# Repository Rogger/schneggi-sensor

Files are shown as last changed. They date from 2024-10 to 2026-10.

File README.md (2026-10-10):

# Schneggi sensor 🐌 
A Zigbee sensor integrated with Home Assistant for monitoring temperature, humidity, and optional CO2.

- High accuracy temperature and humidity measurements ([Sensirion SHTC3](https://www.sensirion.com/products/catalog/SHTC3/))
- High accuracy CO2 measurement ([Sensirion SCD40](https://sensirion.com/products/catalog/SCD40)) - optional board
  - CO2 firmware exposes two temperatures: SHTC3 ambient temperature on endpoint 1
    and SCD40 temperature on endpoint 2. The SCD40 reading uses the same sample as
    CO2 and can be affected by self-heating and enclosure conditions; use SHTC3
    as the primary ambient reading. The existing SHTC3 humidity entity is unchanged.
- Low power consumption and long battery life for the non-CO2 variant
  - Hardware: nRF52840 chip, low-current linear regulator, battery monitor with on/off capability 
  - Software: Zigbee sleepy end device for the non-CO2 variant
  - Measured: 3uA average over 1 minute without CO2 (before OTA support)
- The non-CO2 variant can be powered with 3V to 6V (JST connector), e.g. 350mAh li-poly.
- The CO2 variant is USB-C powered. It advertises DC power, keeps its Zigbee receiver on while idle, and does not report a battery.
- Small footprint (3,5cm x 3cm )
- Tested with [Home Assistant](https://www.home-assistant.io/) and [SkyConnect](https://www.home-assistant.io/skyconnect/)

After upgrading CO2 firmware to a build with the second temperature endpoint,
Home Assistant ZHA must discover endpoint 2. Re-interview/reconfigure the device;
if the endpoint list remains cached, remove and pair the device again. Both
temperature entities use the standard Temperature Measurement cluster, so no
custom quirk is required. You can rename them in HA to **Temperature SHTC3** and
**Temperature SCD40**; endpoint 1 is SHTC3 and endpoint 2 is SCD40. The new reading
uses the same sampling interval, 0.1 °C fallback change threshold, daily refresh,
and standard Configure Reporting support as the existing temperature reading.

## Battery power management

The non-CO2 debug and production profiles enable I2C runtime power management.
The application enables it on the sensor bus; the TWIM driver suspends the
controller and applies its sleep pin configuration between transfers.
Polling, sampling intervals, and SHTC3 measurement accuracy are unchanged.

Failed SHTC3 fetches attempt a sleep command after a 13 ms settling delay,
working around the NCS 2.9.2 driver's missing error-path cleanup without changing
the shared SDK. Cleanup is best-effort: an inaccessible sensor cannot be forced
to sleep. The original fetch error is retained and no failed sample is reported.
The command and conversion timing follow the
[SHTC3 datasheet](https://sensirion.com/file/datasheet_shtc3).

Battery-profile rejoin delays grow from 1 second exponentially to a one-hour
cap (1, 2, 4, ..., 1024, 2048, 3600 seconds). Successful reconnection resets the
backoff. After prolonged outages, recovery may therefore wait up to an hour
before the next attempt, plus commissioning time. USB-powered CO2 profiles keep
their 15-minute cap and do not enable I2C runtime PM or battery monitoring.

Battery measurements run hourly in debug builds and daily in production builds.
If sampling or updating either battery attribute fails, the firmware retries on
the next sensor cycle (one or ten minutes respectively). A successful update
starts the next battery interval. The firmware attempts to disable the divider
on every path and logs cleanup failures.

The firmware restarts if Zigbee startup or scheduling a required measurement,
rejoin, or watchdog alarm fails, so it cannot stay running indefinitely without
that work. Ordinary join failures still use the rejoin backoff described above.
Alarm replacement removes previous instances and uses overflow-safe conversion
for the full supported sampling range of 1–1440 minutes. Repeated Identify
requests keep one blink alarm; scheduling failure stops the LED animation.

Validate on hardware before relying on battery-life estimates: compare at least
an hour of production-profile current capture before/after, with the debugger
disconnected; check repeated sensor reads, transient I2C failures, and recovery
after a prolonged coordinator outage. Host tests cannot verify physical sleep
current or bus suspend/resume behavior.

## Zigbee reporting

ZHA can configure the standard minimum interval, maximum interval, and
reportable change for endpoint 1's Temperature Measurement (`0x0402`) and
Relative Humidity Measurement (`0x0405`) measured-value (`0x0000`) attributes.
Their changes are in hundredths of a degree Celsius and hundredths of a percent
relative humidity. For settings that differ from ZBOSS's defaults, ZBOSS applies
them to every new sensor reading. Without a configuration, or after reporting
is restored to defaults, the firmware retains its 0.1 °C / 1% change thresholds
and 24-hour refresh. A request for ZBOSS's exact default settings (5-second
minimum, no periodic maximum, zero change) is indistinguishable from a reset
and also uses the firmware fallback.

The CO2 Concentration Measurement (`0x040D`) measured value is refreshed on
every sample, so its Zigbee minimum and maximum reporting intervals can be
configured. NCS 2.9.2's ZBOSS treats the single-precision CO2 value as a
changed/unchanged attribute and does not apply a numeric reportable-change
threshold to it. The sensor still samples every minute in debug builds and
every ten minutes in production builds; configuring a shorter reporting
interval does not produce a newer measurement.

## PCB
The PCB was designed with KiCad 7 and manufactured/assembled with JLCPCB. All relevant files can be found in the [repo](hardware)

base
co2

## HomeAssistant



## Case




## Build
This project uses a **west workspace** (manifest in `west.yml`) and a local Makefile wrapper.

### 1) One-time workspace setup
From the project directory:

```bash
west init -l .
make west-update
```

This initializes a west workspace in the parent directory and fetches all required modules
(including `modules/sensirion_drivers` for SCD4X/CO2 builds).

The Makefile uses the parent west workspace when `../.west` exists. To use a
different NCS workspace, pass `NCS_WORKSPACE=/path/to/workspace`.
Builds compare the cached sysbuild source with the selected NCS workspace and
regenerate incompatible project build directories automatically. West's
automatic pristine mode handles other cache incompatibilities.

### 2) Build
Firmware builds now include signed MCUboot/Zigbee OTA support. Supply
`OTA_SIGNING_KEY=/absolute/private/schneggi.pem` to the build commands below.
For development only, use `OTA_ALLOW_TEST_KEY=ON` to opt into the public SDK key.
See [OTA setup, signing, ZHA configuration, and recovery](docs/ota.md).
Interrupted transfers can resume from the last completed 4 KiB flash page after
retrying Install in Home Assistant, including after a sensor power cycle. The
running firmware must already include resume support.

```bash
cd <project-dir>
make build-debug OTA_ALLOW_TEST_KEY=ON
```

Default output:
- `build_debug/merged.hex`
- `build_debug/schneggi-sensor/zephyr/zephyr.elf`

### Build Profiles

Convenience targets:

- `make build-debug`
  - Debug build without CO2 / SCD4X
- `make build-debug-co2`
  - Debug build with CO2 / SCD4X
- `make build-production`
  - Production build without CO2 / SCD4X
- `make build-production-co2`
  - Production build with CO2 / SCD4X

Equivalent flash targets:

```bash
make flash-debug
make flash-debug-co2
make flash-production
make flash-production-co2
```

For the CO2 production firmware:

```bash
make build-production-co2 OTA_SIGNING_KEY=/absolute/private/schneggi.pem
make flash-production-co2
```

### 3) Test (host unit tests)

```bash
make test
```

The host tests cover reporting thresholds and counter wraparound, battery conversion,
CO2 attribute validation, Zigbee signal handling, OTA behavior for both power profiles,
and rejoin retry/cancellation behavior. They also exercise sensor fetch/read failures,
failed attribute writes, custom reporting and resets, exact fixed-point conversion,
battery ADC/GPIO error cleanup and retry timing, and OTA package validation/index updates.
OTA resume tests simulate resets throughout a download, torn flash writes and
checkpoint commits, corrupted saved data, and maximum-size images.
Runtime tests cover failed startup, alarm exhaustion, cancellation failures,
duplicate reconnect signals, and long scheduling intervals. The Python suite also
checks that PCB rule-check failures prevent manufacturing exports under parallel make.
CI runs them in Debug and Release and builds all four firmware profiles. ADC/GPIO
behavior, network recovery over the radio, and sleep current still require hardware tests.

Version tags also run the [GitHub release workflow](docs/releases.md), which publishes
clearly labeled public-development-key firmware, a ready-to-copy ZHA OTA ZIP,
and checksums after validation. Releases preserve the separate CO2/non-CO2 firmware versions.

`make clean` accepts only `build` or `build_*` directories inside this project.

### 4) Flash

```bash
make flash-debug
```

For a specific J-Link probe:

```bash
make flash-production-co2 SNR=<your_jlink_serial>
```

### Useful overrides

```bash
make build BUILD_DIR=build_custom
make build CONF_FILE=prj_production_no_scd4x.conf OVERLAY='boards/adafruit_feather_nrf52840.overlay;boards/no_scd4x.overlay'
make build-production-co2 NCS_WORKSPACE=/path/to/workspace
make flash SNR=<your_jlink_serial>
```

### Keep dependencies in sync
After updating `west.yml`:

```bash
make west-update
```

## Resources
- The PCB design was inspired by [Getting Started With nRF52 MCU in a PCB](https://resources.altium.com/p/getting-started-nrf52-mcu-pcb#getting-started-schematics)
- The repos [zigbee-plant-sensor](https://github.com/stanvn/zigbee-plant-sensor) and [b-parasite](https://github.com/rbaron/b-parasite) are a great start
- The [Zyphr driver for SCD40](https://github.com/nobodyguy/sensirion_zephyr_drivers) 
- The [nRF Sniffer](https://developer.nordicsemi.com/nRF_Connect_SDK/doc/latest/nrf/protocols/zigbee/tools.html) with [https://www.wireshark.org](Wireshark) is a helpful tool to debug Zigbee communication
- The [ZigBee specification 22 1.0](https://csa-iot.org/wp-content/uploads/2022/01/docs-05-3474-22-0csg-zigbee-specification-1.pdf) and [ZigBee Cluster Library R8](https://zigbeealliance.org/wp-content/uploads/2021/10/07-5123-08-Zigbee-Cluster-Library.pdf)

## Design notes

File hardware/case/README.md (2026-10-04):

# Schneggi sensor case

`bottom.stl` and `top.stl` are the printable enclosure parts for the latest PCB.
Keep their relative placement when reviewing the assembly in a CAD viewer or
slicer.

No editable CAD source or generator for these parts is included in this repository.

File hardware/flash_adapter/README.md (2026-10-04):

# Flash Adapter PCB

This KiCad project is intended to be exported for JLCPCB with KiCad 9.

Use KiCad 9 from your `PATH`:

```sh
kicad-cli version
```

The expected version for the checked-in production files is KiCad CLI `9.0.9`.

## Generate JLCPCB Files

These commands follow JLCPCB's KiCad 9 Gerber/drill preparation guidance:

- Run DRC before generating manufacturing files.
- Export the standard fabrication layers: copper, paste, silkscreen, solder mask, and `Edge.Cuts`.
- Use Protel filename extensions for Gerbers.
- Use extended X2 format and include netlist attributes.
- Generate Excellon drill output with absolute origin, millimeters, decimal zeros format, and alternate oval-hole mode.
- Use the drill/place-file origin so Gerber, drill, and CPL coordinates are positive and board-relative.
- Format the BOM as `Comment,Designator,Footprint,JLCPCB Part #（optional）`.
- Format the CPL as `Designator,Mid X,Mid Y,Layer,Rotation`, with `mm` coordinate suffixes.
- Zip only the Gerber layers and merged Excellon drill file before upload.

Reference: <https://jlcpcb.com/help/article/how-to-generate-gerber-and-drill-files-in-kicad-9>
BOM sample: <https://static.jlcpcb.com//video/Sample-BOM_JLCSMT.xlsx>
CPL sample: <https://static.jlcpcb.com//video/JLCSMT_Sample_CPL1.xlsx>

From `hardware/flash_adapter`:

```sh
make jlcpcb
```

The `Makefile` stops before export if DRC errors or ERC violations are found.
It runs the sequence below. For an AppImage installation, override the command:

```sh
make jlcpcb KICAD_CLI='/path/to/AppRun kicad-cli'
```

```sh
kicad-cli pcb drc --severity-error --schematic-parity --exit-code-violations --output flash_adapter-drc.rpt flash_adapter.kicad_pcb
kicad-cli sch erc --severity-all --exit-code-violations --output flash_adapter-erc.rpt flash_adapter.kicad_sch

rm -f jlcpcb/gerber/*
kicad-cli pcb export gerbers --output jlcpcb/gerber --layers F.Cu,B.Cu,F.Paste,B.Paste,F.Silkscreen,B.Silkscreen,F.Mask,B.Mask,Edge.Cuts --use-drill-file-origin flash_adapter.kicad_pcb
kicad-cli pcb export drill --output jlcpcb/gerber --format excellon --drill-origin plot --excellon-units mm --excellon-zeros-format decimal --excellon-oval-format alternate flash_adapter.kicad_pcb
kicad-cli sch export bom --fields Value,Reference,Footprint,'LCSC Part' --labels Comment,Designator,Footprint,'JLCPCB Part #（optional）' --output jlcpcb/production_files/BOM-flash_adapter.csv flash_adapter.kicad_sch
sed -i 's/"//g' jlcpcb/production_files/BOM-flash_adapter.csv

kicad-cli pcb export pos --side front --format csv --units mm --smd-only --use-drill-file-origin --output /tmp/CPL-flash_adapter.raw.csv flash_adapter.kicad_pcb
awk -F, 'BEGIN { print "Designator,Mid X,Mid Y,Layer,Rotation" } NR > 1 { gsub(/"/, ""); layer = ($7 == "top" ? "Top" : ($7 == "bottom" ? "Bottom" : $7)); printf "%s,%.4fmm,%.4fmm,%s,%.0f\n", $1, $4, $5, layer, $6 }' /tmp/CPL-flash_adapter.raw.csv > jlcpcb/production_files/CPL-flash_adapter.csv

rm -f jlcpcb/production_files/GERBER-flash_adapter.zip
zip -j -q jlcpcb/production_files/GERBER-flash_adapter.zip jlcpcb/gerber/*.gtl jlcpcb/gerber/*.gbl jlcpcb/gerber/*.gtp jlcpcb/gerber/*.gbp jlcpcb/gerber/*.gto jlcpcb/gerber/*.gbo jlcpcb/gerber/*.gts jlcpcb/gerber/*.gbs jlcpcb/gerber/*.gm1 jlcpcb/gerber/*.drl
```

The Gerber package uses JLCPCB-style Protel extensions and a single merged Excellon drill file.
The BOM and CPL match the JLCPCB sample column names and column order.

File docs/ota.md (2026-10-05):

# Firmware updates through Home Assistant ZHA

Schneggi uses NCS 2.9.2's Zigbee FOTA client on endpoint 5, cluster `0x0019`,
and MCUboot with ECDSA P-256 signatures and swap using move. Endpoint 1 retains
the sensor clusters. Home Assistant supplies the image and starts installation
through its firmware update entity. No custom ZHA quirk is required by this design.

## One-time installation and signing key

Existing firmware has no OTA bootloader. Install the first OTA-capable
`merged.hex` using the wired programmer. Application-only HEX/BIN files cannot
perform this migration. Back up device flash before migration if retaining the
existing pairing is important; do not use `erase` or `erase-and-flash`.

Generate an ECDSA P-256 private key with MCUboot's `imgtool keygen -t ecdsa-p256
-k /absolute/private/schneggi.pem` (available in the NCS toolchain environment).
Keep this key outside the repository and retain a secure backup. The same key
must sign all subsequent updates for devices installed with it. Losing or
changing it requires another wired installation; bootloader OTA is not supported.

```sh
make build-production OTA_SIGNING_KEY=/absolute/private/schneggi.pem
make flash-production
```

Use `build-production-co2` / `flash-production-co2` for the CO2 board.
Select the correct programmer with `SNR=...`. Flash commands program and erase
only affected sectors. The partition layout keeps ZBOSS network data at
`0xf7000–0xfefff` and product configuration at `0xff000–0xfffff`.
Pairing retention through migration still needs validation on the device.

For a disposable development device, explicitly opt into the publicly known
SDK key:

```sh
make build-debug OTA_ALLOW_TEST_KEY=ON
```

CI artifacts and automated GitHub release assets also use that public key and
are labeled as development firmware, including the production power profiles.
`OTA_ALLOW_TEST_KEY` defaults to `OFF`; ordinary builds
require a private key. Use a separate build directory when changing signing keys.

## Build an update

Increase `CONFIG_MCUBOOT_IMGTOOL_SIGN_VERSION` in the desired profile's `prj_*.conf`,
for example from `1.0.0` to `1.0.1`. Keep debug and production versions aligned
within each hardware variant; CO2 and non-CO2 have separate version histories.
Rebuild with the original signing key:

```sh
make build-production OTA_SIGNING_KEY=/absolute/private/schneggi.pem
make ota-package BUILD_DIR=build_production
make verify-ota BUILD_DIR=build_production OTA_SIGNING_KEY=/absolute/private/schneggi.pem
```

This creates `build_ota_package/index.json` and the corresponding `.zigbee` file.
To create a combined index for both production variants:

```sh
python3 scripts/package_ota.py build_production build_production_co2
```

The tool validates the OTA header, hardware/profile identifiers, image sizes,
the generated DFU payload (one application image with ID 0 and its exact size),
and agreement between MCUboot and Zigbee versions. Conflicting filenames or
existing firmware are rejected before staging files. Firmware files and the index
are installed atomically, so interrupted writes can be retried. Identical firmware
files are left untouched when packaging again.
MCUboot verifies the cryptographic signature on-device before booting a candidate.
The index includes a checksum for ZHA's file-integrity validation.

Versions use `major.minor.patch`, encoded as `(major << 24) | (minor << 16) | patch`.
Major and minor are 8-bit fields; patch is 16-bit. Do not use a `+build` suffix:
Nordic's Zigbee version ignores that suffix. Equal and older versions are refused
by the OTA client. To distribute a fix that restores earlier behavior, release
that code with a new, higher version. Automatic MCUboot trial rollback is separate
from this OTA version policy.

| Profile | Image type |
| --- | --- |
| Production, without CO2 | `0x0101` |
| Production, with CO2 | `0x0102` |
| Debug, without CO2 | `0x8101` |
| Debug, with CO2 | `0x8102` |

Hardware version is `1`. Manufacturer ID `0xFFF1` is a development identifier,
not a CSA assignment to FuZZi. Keep this feed private to your devices; a commercial
release should use an assigned manufacturer ID. The index also matches the
`FuZZi` manufacturer name and `Schneggi Sensor` model. Changing these identifiers
or moving between profiles requires a deliberate migration, normally wired.

Starting with 1.0.2, OTA files and indexes omit the optional minimum/maximum
hardware-version range. NCS 2.9.2's periodic Query Next Image request omits its
hardware version, and zigpy rejects a restricted image when that field is absent.
Removing only the range from the index is insufficient: zigpy also checks the
downloaded OTA header. Compatibility is enforced by manufacturer and image type;
the four image types above are reserved for these hardware-version-1 profiles.
Assign new image types for future incompatible hardware. The client's hardware
version remains 1 for queries triggered by Image Notify. The packager continues
to accept older files with a hardware range of 1–1 for manual notification tests.

## Configure ZHA

Copy the contents of `build_ota_package/` into `/config/zigbee_ota/` on the Home
Assistant host. These are paths **inside Home Assistant**, not on the build PC.
For a different destination, generate the index with `--ha-directory /your/path`.
Merge this into `configuration.yaml`, preserving any existing ZHA configuration:

```yaml
zha:
  zigpy_config:
    ota:
      extra_providers:
        - type: zigpy_local
          index_file: /config/zigbee_ota/index.json
```

Restart Home Assistant to load the provider. After the initial wired migration,
check that ZHA sees endpoint 5's OTA client cluster. Re-interview/reconfigure the
device if needed; if the cached endpoint list remains stale, removal and pairing
again may be necessary. Confirm that the device has a firmware update entity.

The device discovers the OTA server on joining/rebooting, retries discovery every
24 hours if necessary, and queries a discovered server hourly. ZHA can then show
the newer image. Select **Install** on the update entity. Sleepy-device polling
on the non-CO2 variant can delay the start; a missed notification may require
retrying after the device wakes. Its production long polling interval is two
minutes. CO2 firmware from 2.0.0 keeps the receiver on while idle, so it should
accept the notification promptly.

The 2.0.0 CO2 image also changes endpoint 1's power source to DC, removes its
Power Configuration cluster, and increments the endpoint descriptor version.
After updating an existing device, reconfigure or re-interview it in ZHA so the
cached battery entity can be removed. If ZHA keeps the old cluster list, remove
and pair the device again.

To test automatic discovery from 1.0.1, publish the 1.0.2 package and restart
Home Assistant to load its index. Keep the sensor powered and wait for its next
hourly query; do not send the manual Image Notify command. Confirm that ZHA shows
`0x01000002`, then install it. The firmware entity may remain `unknown` until a
query is received. A successfully loaded provider alone does not establish that
the image matches the sensor. Enable ZHA debug logging to inspect the query and
image selection if discovery does not occur.

The battery variant uses a temporary 100 ms polling interval during transfers,
then restores its normal interval on error or completion. The USB-powered CO2
variant leaves its receiver on and does not use the sleepy-device polling controls.
During download, five minutes without an accepted image block causes an abort and
reboot to clear the session. Successful image validation cancels that deadline;
ZBOSS then honors the server's installation time, including indefinite deferral.
A separate five-minute deadline resets the session by rebooting if the server's
Upgrade End response is missing. It checks the ZBOSS state, so an acknowledged
indefinite deferral or scheduled installation does not trigger recovery.
The battery client uses a bounded 30-second turbo-poll window to receive the
Upgrade End response, then returns to normal polling while waiting. The USB
variant keeps receiving continuously. CO2 firmware from 2.0.4 and non-CO2 firmware
from 1.0.6 support OTA resume and retain completed
4 KiB flash pages across server aborts, timeout recovery, and device power loss.
Retry **Install** in Home Assistant after the sensor reconnects. Each retry first
downloads and compares the OTA and DFU headers, then jumps to the last committed
page. The incomplete page is downloaded again. Before the first page has been
committed, a retry starts from zero. Home Assistant may initially display 0% until
the device advances its requested offset.

The checkpoint journal uses the existing reserved page at `0xf6000`; neither
MCUboot slots nor Zigbee storage move. Each committed page has a CRC-protected
record written after its data, with a separate commit marker. Incomplete journal
records are ignored. Corrupt stored data, an invalid journal header, a changed
package header, or a different image identity cause a fresh download. Invalid
incoming images discard their checkpoint.
Firmware images must remain immutable for a given manufacturer, image type,
version and size; publish changed contents with a higher version. MCUboot still
verifies the candidate signature before booting it, and trial firmware cannot
write the secondary slot until confirmation. The receiver accepts the same
canonical, single-application DFU packages as `scripts/package_ota.py`.

The firmware currently running on the sensor must include this resume code;
installing it from older firmware uses that older client's restart behavior.
Successful leave events discard retained progress. If a transfer or installation
is active, the device also aborts and reboots after normal leave handling to clear
SDK protocol state; failed leave attempts preserve the session.
Installation briefly interrupts sensor reporting and then rejoins using
persistent network settings.

See [ZHA firmware updates](https://www.home-assistant.io/integrations/zha/#ota-updates-of-zigbee-device-firmware)
and [zigpy provider configuration](https://github.com/zigpy/zigpy/wiki/OTA-Configuration).
An HTTPS index via `zigpy_remote` can be added later. The [release workflow](releases.md)
publishes downloadable assets, including a ZIP for the local ZHA provider; it does
not change Home Assistant remotely.

## Recovery, flash limits, and hardware acceptance

Bench test on 2026-09-28: the USB-powered debug CO2 sensor successfully updated
from 1.0.0 to 1.0.1 through ZHA after a manual Image Notify. The installed version
changed to `0x01000001`, CO2/temperature/humidity reporting resumed, and reporting
and pairing survived a subsequent power cycle. The first installation attempt
failed; the retry completed. On 2026-10-01, ZHA discovered the 1.0.2 image after
its local provider was updated, without a manual Image Notify. Installation again
started on the second attempt, and Home Assistant reported `0x01000002` with
changing sensor readings. This confirms automatic discovery and the basic update
path for that device. The remaining recovery tests below require separate validation.

The 1 MiB internal flash contains a 48 KiB bootloader, two 468 KiB slots, a
reserved page, and the existing 36 KiB Zigbee storage. The image-size check allows
460 KiB including the MCUboot header/signature, reserving pages for move-swap and
its trailer. Keep `pm_static.yml` unchanged for future OTA releases.

MCUboot requests a trial boot. New downloads and image blocks are rejected until
the running image is confirmed, protecting the previous firmware in the secondary
slot. A later OTA query can retry after confirmation. Ten seconds after Zigbee
stack startup, the application confirms the candidate only if required peripheral
devices are ready, plus battery-monitor initialization on non-CO2 firmware.
This is a local startup check, not a test of successful sensor conversions or
coordinator reachability. Failure reboots without confirmation so MCUboot can
revert. A 120-second hardware watchdog is fed by the Zigbee scheduler every 30
seconds to recover from a hang; MCUboot feeds it during swaps. A fault after
confirmation does not automatically
restore the old application.

The health alarm wakes the battery variant every 30 seconds, and its watchdog
stays active during sleep. Previously published current measurements predate OTA
support. Measure idle current again and allow for higher radio current during
updates.

Before deploying to all sensors, test on one device of each hardware variant:

1. Save the current flash, install the initial merged image, and verify sensor
   reporting, retained pairing (or re-pair), and ZHA's OTA endpoint/update entity.
2. Install a higher-version image through ZHA; verify the reported version,
   confirmation, reconnection, and temperature/humidity reporting. Check CO2
   readings on the USB variant and battery reporting on the non-CO2 variant.
3. Interrupt the coordinator during download. Verify timeout recovery and a
   successful retry from the committed offset, with normal polling restored on
   the battery variant. The sensor log reports `Resuming OTA at byte ...`.
4. Interrupt device power during transfer and during the swap. Verify a working
   old or new image and intact pairing data after restart. Retry the interrupted
   download and verify a nonzero requested offset after the headers are received.
5. Offer a wrong-profile image, an older image, a corrupted image, and an image
   signed with a different key. Verify rejection and recovery.
6. Use a deliberately failing trial image on the test device to verify rollback
   after failed startup and watchdog reset; retain wired recovery access.
7. Measure production idle/update current with the debugger disconnected.
8. Drop the Upgrade End response and verify recovery after five minutes. Then
   explicitly defer installation (indefinitely and for more than five minutes)
   and verify that neither case triggers the missing-response recovery.
9. Exercise failed and successful leave attempts during download and deferred
   installation. Failed attempts must preserve the session; successful leaves
   must reset it without executing a stale deferred installation.

Host tests and builds do not establish radio interoperability, physical power-loss
recovery, or battery lifetime. Those checks require the sensor and a running ZHA
installation.

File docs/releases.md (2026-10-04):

# GitHub firmware releases

The **Release firmware** workflow creates a GitHub Release when a version tag
such as `2.0.3` or `v2.0.3` is pushed. It tests and builds the exact tagged commit,
using the same workflow as branch/PR CI. Debug and Release host tests, all four
firmware builds, signature verification, and OTA packaging must succeed before
anything is published.

All downloadable images use the **public MCUboot SDK development key**. This is
also true for the production power profiles; the profile name is not a security
designation. These images can OTA-update devices installed with that same key
and image type. Devices installed with a private key need separately signed
builds. See [OTA setup and compatibility](ota.md).

## Publish a new version

1. Increase `CONFIG_MCUBOOT_IMGTOOL_SIGN_VERSION` in both debug and production
   configurations for each variant that changed. CO2 and non-CO2 have separate
   version histories; leave an unchanged variant's version alone. Merge the
   changes into `main` after testing.
2. Tag that commit and push the tag, for example:

   ```sh
   git switch main
   git pull --ff-only
   git tag -a 2.0.3 -m 'Schneggi 2.0.3'
   git push origin 2.0.3
   ```

3. Follow **Actions → Release firmware**. Once validation and uploads finish,
   the workflow publishes the release with generated change notes, the source
   commit, per-profile versions, and the public-key notice.

The repository tag labels a source snapshot; it does not override firmware
versions. For example, a `2.0.3` release may contain CO2 `2.0.3` and non-CO2
`1.0.5`. Increase each affected variant's firmware version before tagging, or
existing devices running that version will refuse the OTA update.

Alternatively, use **Actions → Release firmware → Run workflow**, select `main`,
and enter an existing tag. It must point to a commit containing the release
packaging scripts. This creates a release for a tag that has not yet been
published. Tags support `major.minor.patch` with an optional `v` prefix; suffixes
such as `-rc1` are not supported by this workflow.

## Downloadable assets

| Asset | Purpose |
| --- | --- |
| `schneggi-ota-public-test-key.zip` | All four `.zigbee` images and `index.json`, ready to extract into HA's `/config/zigbee_ota/` |
| Individual `.zigbee` files and `index.json` | The same local-provider OTA package as separate downloads |
| `schneggi-<profile>-<version>-public-test-key-merged.hex` | Wired installation including MCUboot |
| `schneggi-<profile>-<version>-public-test-key-signed.bin` | Signed application only |
| `schneggi-<profile>-<version>-public-test-key-partitions.yml` | Flash layout for each build |
| `FIRMWARE.md` | Source commit, versions, signing-key notice, and installation guidance |
| `SHA256SUMS` | SHA-256 checksums of all the other assets |

The same flat set of files is available from normal CI under the Actions artifact
`development-firmware-public-test-key`. No local build environment is needed to
download and use them. Home Assistant still needs the [local OTA provider](ota.md#configure-zha)
configured and the package copied to its configuration directory.

## Failed runs and retries

A failed build does not create a release. Publication starts with a draft and
only makes it public after all uploads succeed. A rerun may replace matching
assets in that draft to complete a failed upload. It refuses to modify an already
published release: use a new tag and bump affected firmware versions for fixes.
Existing draft release notes are preserved; newly created drafts include the
firmware notice and GitHub-generated change notes. Do not move a tag during a run;
the workflow verifies that it still points to the commit that was built.

Only the publishing job has `contents: write`; test/build jobs have read access.
The built-in `GITHUB_TOKEN` handles publication, so no extra token or signing
secret is required for these public-key development releases.

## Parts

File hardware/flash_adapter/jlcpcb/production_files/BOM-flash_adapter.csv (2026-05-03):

Comment | Designator | Footprint | JLCPCB Part #（optional）
FTSH-105-01-L-DV-K-TR | J1 | schneggi_library:CONN-SMD_FTSH-105-01-L-DV-K-TR | C448647
HX PZ2.54-2x5P WT | J2 | easyeda_import:HDR-SMD_10P-P2.54-H-M-R2-C5-W18.0 | C46061687

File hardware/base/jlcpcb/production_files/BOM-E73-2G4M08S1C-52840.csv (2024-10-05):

Comment | Designator | Footprint | LCSC
100nF | C3 | C_0603_1608Metric | C14663
1uF | C1 | C_0603_1608Metric | C15849
SM04B-SRSS-TB (LF)(SN) | CN2 | CONN-SMD_4P-P1.00_SM04B-SRSS-TB-LF-SN | C160404
180k | R9 | R_0603_1608Metric | C22827
1M0 | R10,R3 | R_0603_1608Metric | C22935
220 | R4 | R_0603_1608Metric | C22962
2.2uF | C2 | C_0603_1608Metric | C23630
10k | R5,R6 | R_0603_1608Metric | C25804
AFC20-S02ACA-00 | X1 | CONN-SMD_AFC20-S02ACA-00 | C2764211
SHTC3-10000 | U3 | DFN-4_L2.0-W2.0-P1.00-BL-EP | C2880044
TS-1187A-B-A-B | RESET1,SW1 | SW-SMD_4P-L5.1-W5.1-P3.70-LS6.5-TL-2 | C318884
XDMCZLNDDF-0.032768MHZ | X2 | CRYSTAL-SMD_L3.2-W1.5-1 | C32346
E73-2G4M08S1C | U1 | WIRELM-SMD_E73-2G4M08S1C | C356849
12pF | C4,C5 | C_0603_1608Metric | C38523
1M5 | R7 | R_0603_1608Metric | C4172
FTSH-105-01-L-DV-K-TR | CN1 | CONN-SMD_FTSH-105-01-L-DV-K-TR | C448647
DMC2400UV-13 | Q1 | SOT-563_L1.6-W1.2-P0.50-LS1.6-BL | C500791
XL-2012SURC | LED1 | LED0805-RD_RED | C84256
TPS70933DBVR | LDO1 | SOT-23-5_L3.0-W1.7-P0.95-LS2.8-BR | C89347

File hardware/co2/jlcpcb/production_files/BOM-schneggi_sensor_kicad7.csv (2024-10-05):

Comment | Designator | Footprint | LCSC
SM04B-SRSS-TB (LF)(SN) | CN2 | CONN-SMD_4P-P1.00_SM04B-SRSS-TB-LF-SN | C160404
10k | R1,R2 | R_0603_1608Metric | C25804
SCD40-D-R2_C3659421 | U1 | LGA-20_L10.1-W10.1-P1.25-TL | C3659421

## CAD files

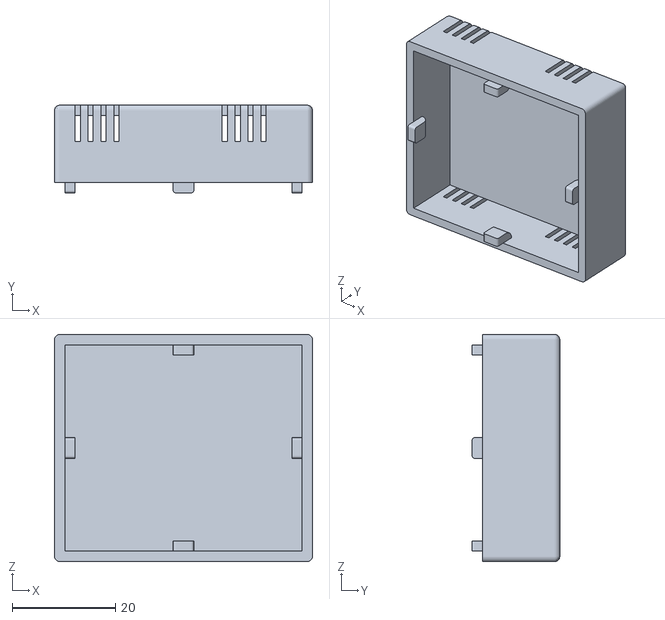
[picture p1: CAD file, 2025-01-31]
hardware/case/top.stl
50.0 x 17.0 x 44.0

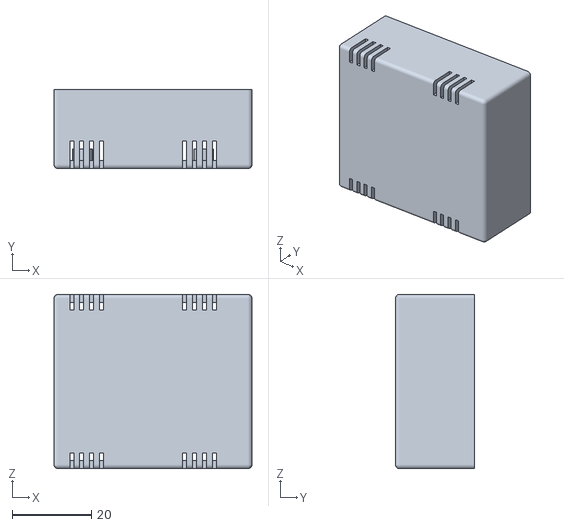
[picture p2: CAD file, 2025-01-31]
hardware/case/bottom.stl
50.0 x 20.0 x 44.0

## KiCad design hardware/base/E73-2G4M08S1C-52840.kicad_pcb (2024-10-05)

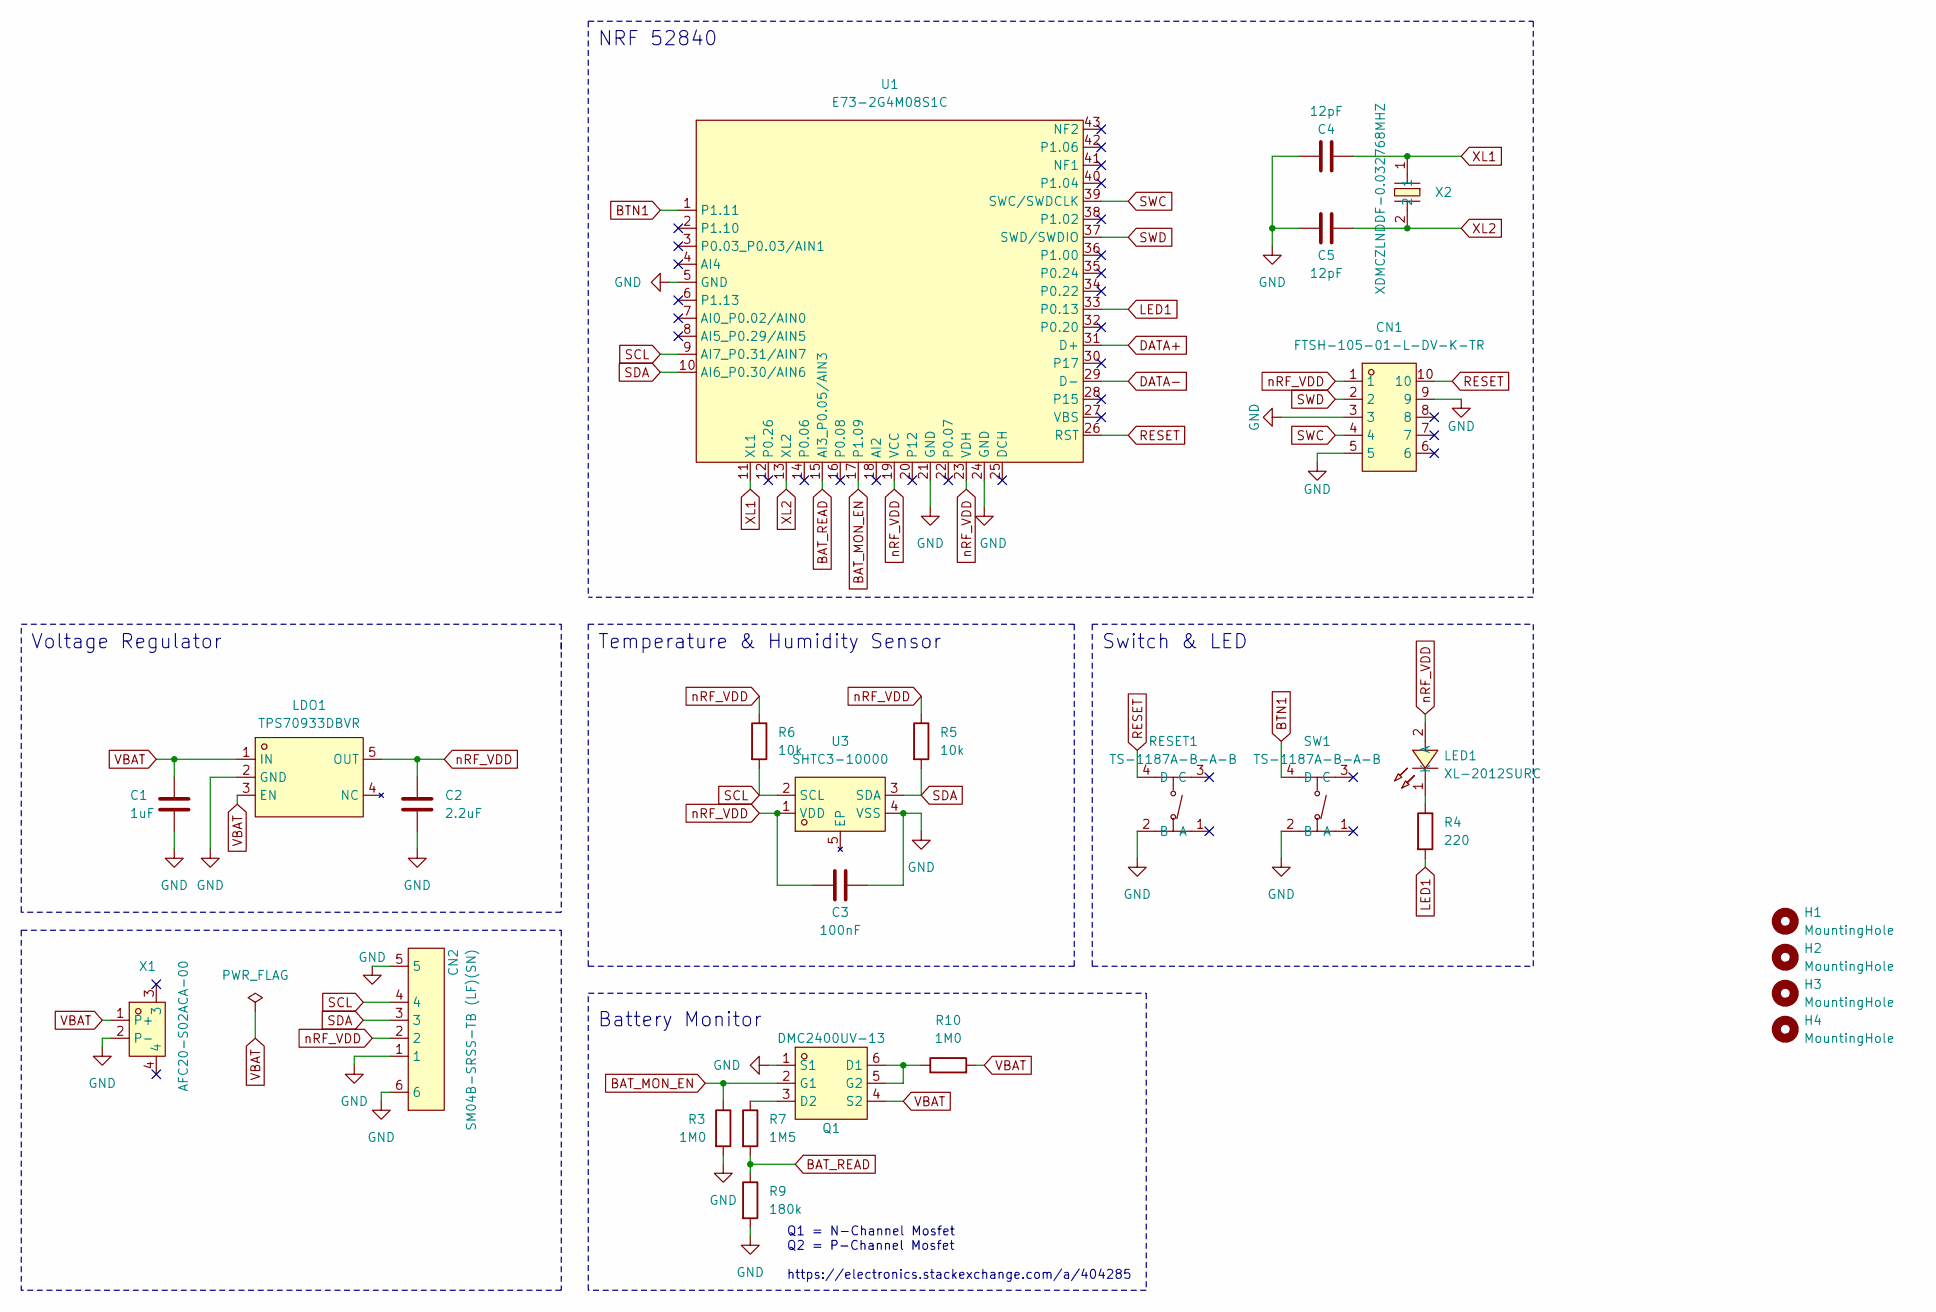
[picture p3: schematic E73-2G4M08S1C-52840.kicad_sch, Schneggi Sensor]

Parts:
C1: 1uF; C_0603_1608Metric; LCSC C15849
C2: 2.2uF; C_0603_1608Metric; LCSC C23630
C3: 100nF; C_0603_1608Metric; LCSC C14663
C4, C5: 12pF; C_0603_1608Metric; LCSC C38523
CN1: FTSH-105-01-L-DV-K-TR; CONN-SMD_FTSH-105-01-L-DV-K-TR; LCSC Part C448647
CN2: SM04B-SRSS-TB (LF)(SN); CONN-SMD_4P-P1.00_SM04B-SRSS-TB-LF-SN; LCSC Part C160404
H1, H2, H3, H4: MountingHole; MountingHole_2.2mm_M2
LDO1: TPS70933DBVR; SOT-23-5_L3.0-W1.7-P0.95-LS2.8-BR; LCSC Part C89347
LED1: XL-2012SURC; LED0805-RD_RED; LCSC C84256
Q1: DMC2400UV-13; SOT-563_L1.6-W1.2-P0.50-LS1.6-BL; LCSC Part C500791
R3, R10: 1M0; R_0603_1608Metric; LCSC C22935
R4: 220; R_0603_1608Metric; LCSC C22962
R5, R6: 10k; R_0603_1608Metric; lcsc C98220
R7: 1M5; R_0603_1608Metric; LCSC C4172
R9: 180k; R_0603_1608Metric; LCSC C22827
RESET1: TS-1187A-B-A-B; SW-SMD_4P-L5.1-W5.1-P3.70-LS6.5-TL-2; LCSC Part C318884
SW1: TS-1187A-B-A-B; SW-SMD_4P-L5.1-W5.1-P3.70-LS6.5-TL-2; LCSC Part C318884
U1: E73-2G4M08S1C; WIRELM-SMD_E73-2G4M08S1C; LCSC Part C356849
U3: SHTC3-10000; DFN-4_L2.0-W2.0-P1.00-BL-EP; LCSC Part C2880044
X1: AFC20-S02ACA-00; CONN-SMD_AFC20-S02ACA-00; LCSC Part C2764211
X2: XDMCZLNDDF-0.032768MHZ; CRYSTAL-SMD_L3.2-W1.5-1; LCSC Part C32346

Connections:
BAT_MON_EN: Q1.2 (G1), R3.1, U1.17 (P1.09)
BAT_READ: R7.2, R9.1, U1.15 (AI3_P0.05/AIN3)
BTN1: SW1.4 (D), U1.1 (P1.11)
DATA+: U1.31 (D+)
DATA-: U1.29 (D-)
GND: C1.2, C2.2, C3.2, C4.1, C5.1, CN1.3, CN1.5, CN1.9, CN2.1, CN2.5, CN2.6, LDO1.2 (GND), Q1.1 (S1), R3.2, R9.2, RESET1.2 (B), SW1.2 (B), U1.5 (GND), U1.21 (GND), U1.24 (GND), U3.4 (VSS), X1.2 (P-)
LED1: R4.2, U1.33 (P0.13)
unnamed: LED1.1 (K), R4.1
unnamed: Q1.5 (G2), Q1.6 (D1), R10.1
unnamed: Q1.3 (D2), R7.1
RESET: CN1.10, RESET1.4 (D), U1.26 (RST)
SCL: CN2.4, R6.2, U1.9 (AI7_P0.31/AIN7), U3.2 (SCL)
SDA: CN2.3, R5.2, U1.10 (AI6_P0.30/AIN6), U3.3 (SDA)
SWC: CN1.4, U1.39 (SWC/SWDCLK)
SWD: CN1.2, U1.37 (SWD/SWDIO)
VBAT: C1.1, LDO1.1 (IN), LDO1.3 (EN), Q1.4 (S2), R10.2, X1.1 (P+)
XL1: C4.2, U1.11 (XL1), X2.1
XL2: C5.2, U1.13 (XL2), X2.2
nRF_VDD: C2.1, C3.1, CN1.1, CN2.2, LDO1.5 (OUT), LED1.2 (A), R5.1, R6.1, U1.19 (VCC), U1.23 (VDH), U3.1 (VDD)

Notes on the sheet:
Q1 = N-Channel Mosfet Q2 = P-Channel Mosfet https://electronics.stackexchange.com/a/404285
Temperature & Humidity Sensor
Switch & LED
Voltage Regulator
Battery Monitor
NRF 52840

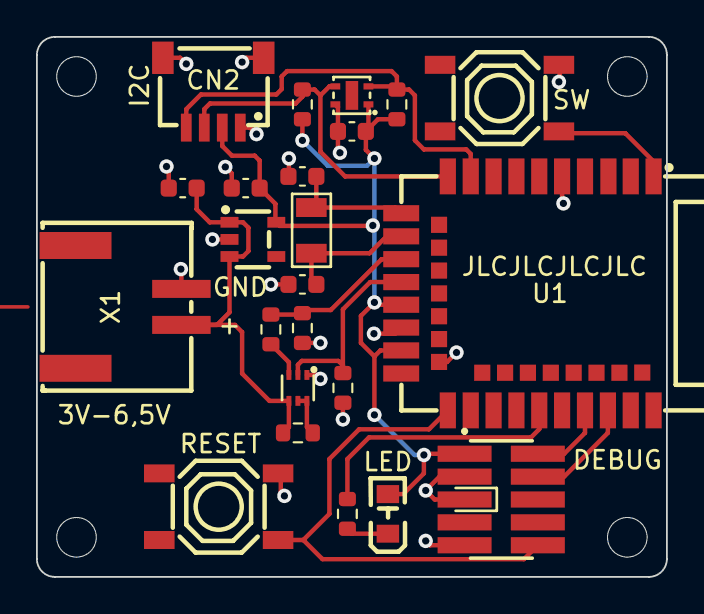
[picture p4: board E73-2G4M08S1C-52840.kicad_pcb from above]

Board: 2 copper layers, 35.0 x 30.0 mm, 27 parts (0 on the bottom side), 17 nets.

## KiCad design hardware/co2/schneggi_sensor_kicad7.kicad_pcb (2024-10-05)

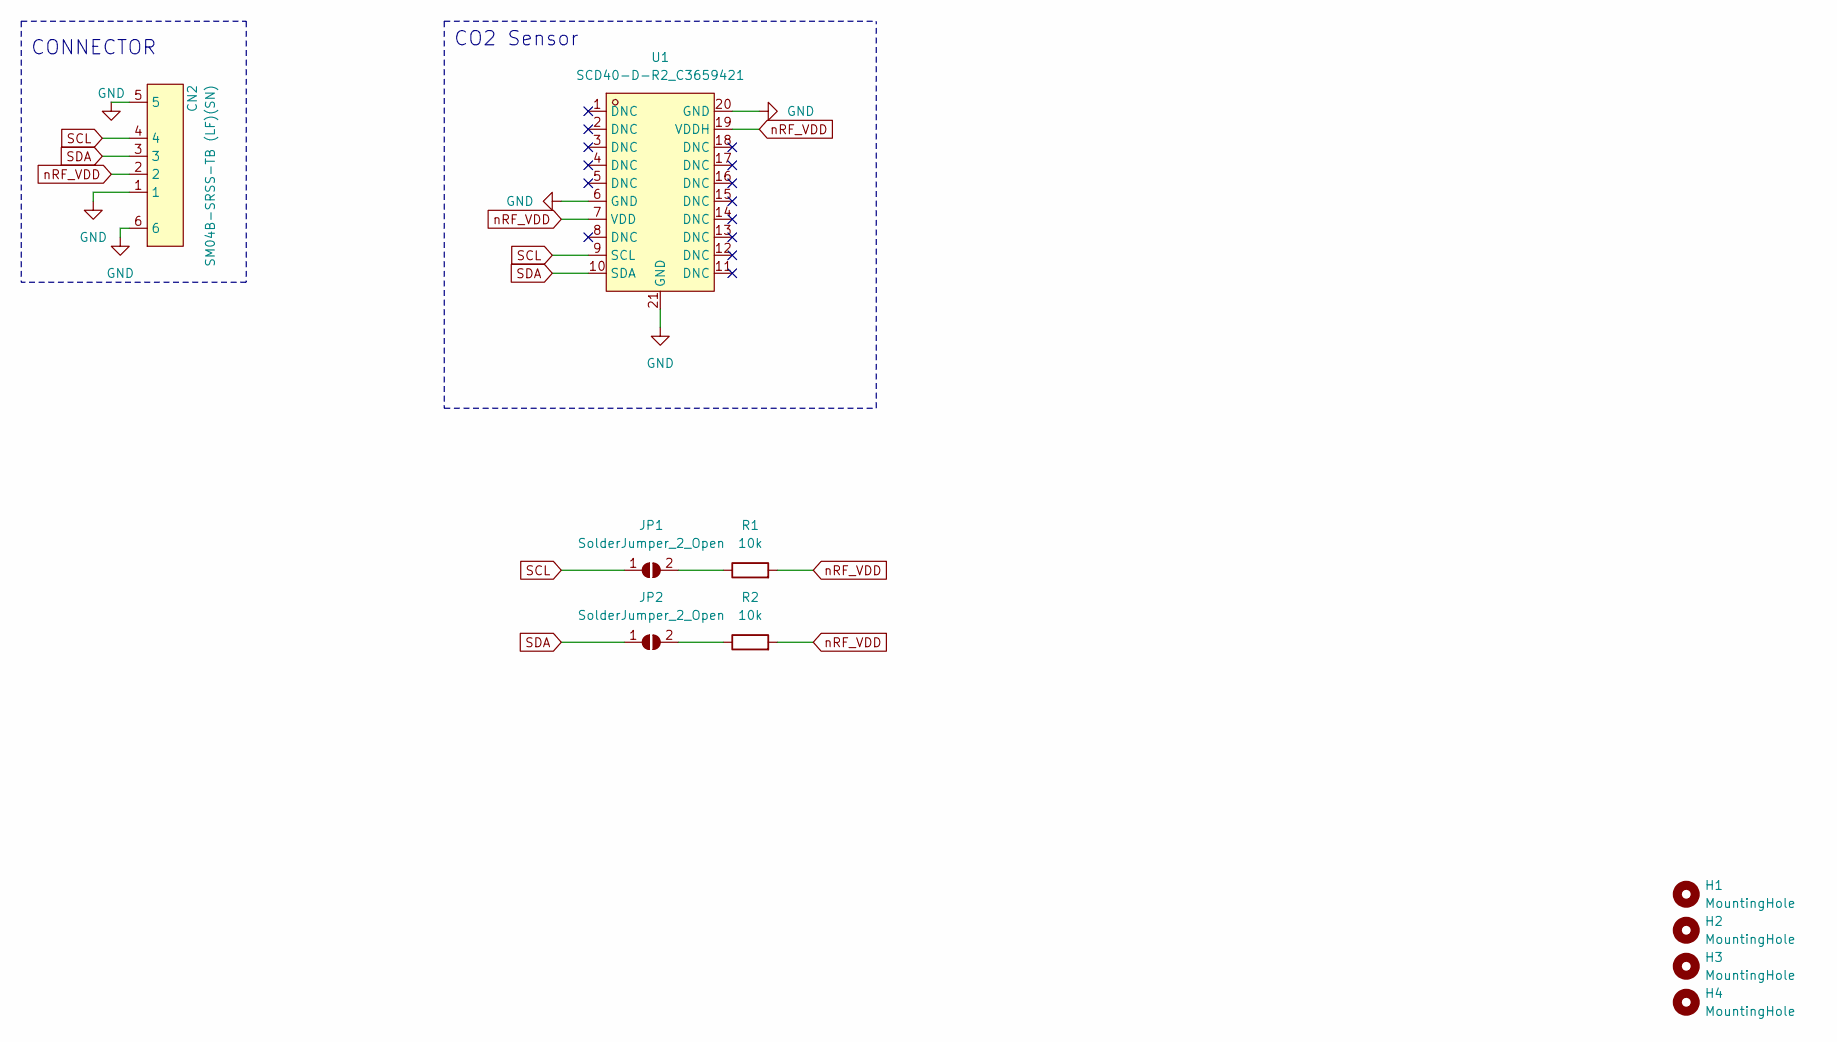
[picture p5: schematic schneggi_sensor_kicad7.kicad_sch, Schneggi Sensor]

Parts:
CN2: SM04B-SRSS-TB (LF)(SN); CONN-SMD_4P-P1.00_SM04B-SRSS-TB-LF-SN; LCSC Part C160404
H1, H2, H3, H4: MountingHole; MountingHole_2.2mm_M2
JP1, JP2: SolderJumper_2_Open; SolderJumper-2_P1.3mm_Open_TrianglePad1.0x1.5mm
R1, R2: 10k; R_0603_1608Metric
U1: SCD40-D-R2_C3659421; LGA-20_L10.1-W10.1-P1.25-TL; LCSC Part C3659421

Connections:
GND: CN2.1, CN2.5, CN2.6, U1.6 (GND), U1.20 (GND), U1.21 (GND)
unnamed: JP1.2 (B), R1.1
unnamed: JP2.2 (B), R2.1
SCL: CN2.4, JP1.1 (A), U1.9 (SCL)
SDA: CN2.3, JP2.1 (A), U1.10 (SDA)
nRF_VDD: CN2.2, R1.2, R2.2, U1.7 (VDD), U1.19 (VDDH)

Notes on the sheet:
CO2 Sensor
CONNECTOR

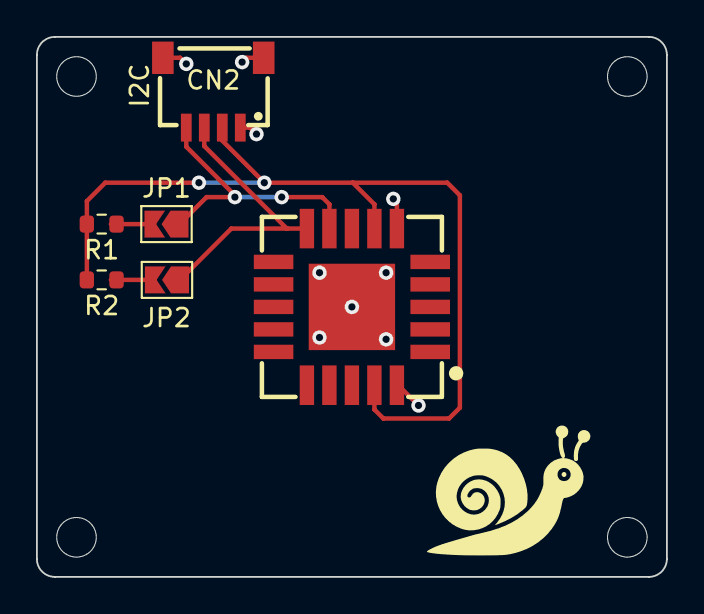
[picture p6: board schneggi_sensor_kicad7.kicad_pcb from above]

Board: 2 copper layers, 35.0 x 30.0 mm, 10 parts (0 on the bottom side), 6 nets.

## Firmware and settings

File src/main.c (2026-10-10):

#include <inttypes.h>
#include <soc.h>
#include <zephyr/types.h>
#include <zephyr/kernel.h>
#include <zephyr/device.h>
#include <zephyr/drivers/sensor.h>
#include <zephyr/drivers/adc.h>
#include <zephyr/drivers/gpio.h>
#include <zephyr/pm/device_runtime.h>
#include "app_environment.h"
#include "app_scd4x.h"
#include "app_battery.h"
#include "app_ota.h"
#include "app_reboot.h"
#include "app_scheduler.h"
#include <zephyr/logging/log.h>
#include <zephyr/sys/util.h>
#include <ram_pwrdn.h>

#include <zboss_api.h>
#include <zboss_api_addons.h>
#include <zb_mem_config_med.h>
#include <zigbee/zigbee_app_utils.h>
#include <zigbee/zigbee_error_handler.h>
#include <zb_nrf_platform.h>
#include "nrf_802154.h"
#include "zb_schneggi_sensor.h"

#include <zcl/zb_zcl_power_config.h>
#include <zcl/zb_zcl_temp_measurement_addons.h>
#include <zcl/zb_zcl_basic_addons.h>
#include "zcl/zb_zcl_concentration_measurement.h"
#include "app_zcl_report.h"
#include "co2_zcl_logic.h"
#include "app_network.h"
#include "zigbee_signal_logic.h"

#define APP_HAS_SCD4X DT_HAS_COMPAT_STATUS_OKAY(sensirion_scd4x)

// Sleep
static const uint32_t SLEEP_INTERVAL_SECONDS = (uint32_t)CONFIG_SENSOR_UPDATE_INTERVAL_MINUTES * 60U;				   // HA minimum = 30s
#if !APP_HAS_SCD4X
static const uint32_t BATTERY_REPORT_INTERVAL_SECONDS = (uint32_t)CONFIG_BATTERY_UPDATE_INTERVAL_HOURS * 60U * 60U; // HA minimum = 3600s
static const uint32_t BATTERY_SLEEP_CYCLES =
	(BATTERY_REPORT_INTERVAL_SECONDS + SLEEP_INTERVAL_SECONDS - 1U) / SLEEP_INTERVAL_SECONDS;
#endif
static const uint32_t SENSOR_REFRESH_INTERVAL_SECONDS = 24U * 60U * 60U;
static const uint32_t SENSOR_REFRESH_CYCLES =
	(SENSOR_REFRESH_INTERVAL_SECONDS + SLEEP_INTERVAL_SECONDS - 1U) / SLEEP_INTERVAL_SECONDS;

#if defined(CONFIG_ZIGBEE_KEEPALIVE_TIMEOUT_MS)
#define APP_ZIGBEE_KEEPALIVE_TIMEOUT_MS ((uint32_t)CONFIG_ZIGBEE_KEEPALIVE_TIMEOUT_MS)
#else
#define APP_ZIGBEE_KEEPALIVE_TIMEOUT_MS (600000U)
#endif

#if defined(ED_AGING_TIMEOUT_64MIN)
#define APP_ZIGBEE_ED_TIMEOUT_VALUE ED_AGING_TIMEOUT_64MIN
#define APP_ZIGBEE_ED_TIMEOUT_DESC "64min"
#else
#define APP_ZIGBEE_ED_TIMEOUT_VALUE ED_AGING_TIMEOUT_32MIN
#define APP_ZIGBEE_ED_TIMEOUT_DESC "32min"
#endif

BUILD_ASSERT(CONFIG_SENSOR_UPDATE_INTERVAL_MINUTES > 0, "CONFIG_SENSOR_UPDATE_INTERVAL_MINUTES must be greater than zero");
#if !APP_HAS_SCD4X
BUILD_ASSERT(CONFIG_BATTERY_UPDATE_INTERVAL_HOURS > 0, "CONFIG_BATTERY_UPDATE_INTERVAL_HOURS must be greater than zero");
BUILD_ASSERT((uint32_t)CONFIG_BATTERY_UPDATE_INTERVAL_HOURS * 60U * 60U >=
					 (uint32_t)CONFIG_SENSOR_UPDATE_INTERVAL_MINUTES * 60U,
			 "CONFIG_BATTERY_UPDATE_INTERVAL_HOURS must not be shorter than CONFIG_SENSOR_UPDATE_INTERVAL_MINUTES");
#endif
BUILD_ASSERT(APP_ZIGBEE_KEEPALIVE_TIMEOUT_MS >= APP_ZIGBEE_LONG_POLL_INTERVAL_MS,
			 "CONFIG_ZIGBEE_KEEPALIVE_TIMEOUT_MS must be >= CONFIG_ZIGBEE_LONG_POLL_INTERVAL_MS");

// ZigBee
#define SCHNEGGI_ENDPOINT 0x01
#define SCHNEGGI_SCD4X_TEMPERATURE_ENDPOINT 0x02
#define SCHNEGGI_BASIC_MANUF_NAME "FuZZi"
#define SCHNEGGI_BASIC_MODEL_ID "Schneggi Sensor"
#define SCHNEGGI_BASIC_DATE_CODE "20240810"

typedef struct
{
	zb_int16_t measure_value;
	zb_int16_t min_measure_value;
	zb_int16_t max_measure_value;
} zb_zcl_rel_humidity_measurement_attr_t;

typedef struct
{
	zb_uint32_t measure_value;
	zb_uint32_t min_measure_value;
	zb_uint32_t max_measure_value;
	zb_uint32_t tolerance;
} zb_zcl_concentration_measurement_attrs_t;

#if !APP_HAS_SCD4X
typedef struct
{
	zb_uint8_t battery_voltage;
	zb_uint8_t battery_size;
	zb_uint8_t battery_quantity;
	zb_uint8_t battery_rated_voltage;
	zb_uint8_t battery_alarm_mask;
	zb_uint8_t battery_voltage_min_threshold;
	zb_uint8_t battery_percentage_remaining;
	zb_uint8_t battery_voltage_threshold1;
	zb_uint8_t battery_voltage_threshold2;
	zb_uint8_t battery_voltage_threshold3;
	zb_uint8_t battery_percentage_min_threshold;
	zb_uint8_t battery_percentage_threshold1;
	zb_uint8_t battery_percentage_threshold2;
	zb_uint8_t battery_percentage_threshold3;
	zb_uint32_t battery_alarm_state;

} zb_zcl_power_config_attr_t;
#endif

typedef struct
{
	zb_zcl_basic_attrs_ext_t basic_attr;
	zb_zcl_identify_attrs_t identify_attr;
	zb_zcl_temp_measurement_attrs_t temp_measure_attrs;
	zb_zcl_rel_humidity_measurement_attr_t humidity_measure_attrs;
	zb_zcl_concentration_measurement_attrs_t concentration_measure_attrs;
#if APP_HAS_SCD4X
	zb_zcl_temp_measurement_attrs_t scd_temperature_attrs;
	zb_zcl_identify_attrs_t scd_identify_attrs;
#endif
#if !APP_HAS_SCD4X
	zb_zcl_power_config_attr_t power_config_attr;
#endif
} schneggi_device_ctx_t;

static schneggi_device_ctx_t dev_ctx;

ZB_ZCL_DECLARE_BASIC_ATTRIB_LIST_EXT(
	basic_attr_list,
	&dev_ctx.basic_attr.zcl_version,
	&dev_ctx.basic_attr.app_version,
	&dev_ctx.basic_attr.stack_version,
	&dev_ctx.basic_attr.hw_version,
	dev_ctx.basic_attr.mf_name,
	dev_ctx.basic_attr.model_id,
	dev_ctx.basic_attr.date_code,
	&dev_ctx.basic_attr.power_source,
	dev_ctx.basic_attr.location_id,
	&dev_ctx.basic_attr.ph_env,
	&dev_ctx.basic_attr.sw_ver);

ZB_ZCL_DECLARE_IDENTIFY_ATTRIB_LIST(
	identify_attr_list,
	&dev_ctx.identify_attr.identify_time);

ZB_ZCL_DECLARE_TEMP_MEASUREMENT_ATTRIB_LIST(
	temp_measurement_attr_list,
	&dev_ctx.temp_measure_attrs.measure_value,
	&dev_ctx.temp_measure_attrs.min_measure_value,
	&dev_ctx.temp_measure_attrs.max_measure_value,
	&dev_ctx.temp_measure_attrs.tolerance);

ZB_ZCL_DECLARE_REL_HUMIDITY_MEASUREMENT_ATTRIB_LIST(
	humidity_measurement_attr_list,
	&dev_ctx.humidity_measure_attrs.measure_value,
	&dev_ctx.humidity_measure_attrs.min_measure_value,
	&dev_ctx.humidity_measure_attrs.max_measure_value);

#if APP_HAS_SCD4X
ZB_ZCL_DECLARE_TEMP_MEASUREMENT_ATTRIB_LIST(
	scd_temperature_attr_list,
	&dev_ctx.scd_temperature_attrs.measure_value,
	&dev_ctx.scd_temperature_attrs.min_measure_value,
	&dev_ctx.scd_temperature_attrs.max_measure_value,
	&dev_ctx.scd_temperature_attrs.tolerance);

ZB_ZCL_DECLARE_IDENTIFY_ATTRIB_LIST(
	scd_identify_attr_list,
	&dev_ctx.scd_identify_attrs.identify_time);

ZB_ZCL_DECLARE_CONCENTRATION_MEASUREMENT_ATTRIB_LIST(concentration_measurement_attr_list,
													 &dev_ctx.concentration_measure_attrs.measure_value,
													 &dev_ctx.concentration_measure_attrs.min_measure_value,
													 &dev_ctx.concentration_measure_attrs.max_measure_value,
													 &dev_ctx.concentration_measure_attrs.tolerance);
#endif

#if !APP_HAS_SCD4X
/* Define 'bat_num' as empty in order to declare default battery set attributes. */
/* According to Table 3-17 of ZCL specification, defining 'bat_num' as 2 or 3 allows */
/* to declare battery set attributes for BATTERY2 and BATTERY3 */
#define bat_num

ZB_ZCL_DECLARE_POWER_CONFIG_BATTERY_ATTRIB_LIST_EXT(
	power_config_attr_list,
	&dev_ctx.power_config_attr.battery_voltage,
	&dev_ctx.power_config_attr.battery_size,
	&dev_ctx.power_config_attr.battery_quantity,
	&dev_ctx.power_config_attr.battery_rated_voltage,
	&dev_ctx.power_config_attr.battery_alarm_mask,
	&dev_ctx.power_config_attr.battery_voltage_min_threshold,
	&dev_ctx.power_config_attr.battery_percentage_remaining,
	&dev_ctx.power_config_attr.battery_voltage_threshold1,
	&dev_ctx.power_config_attr.battery_voltage_threshold2,
	&dev_ctx.power_config_attr.battery_voltage_threshold3,
	&dev_ctx.power_config_attr.battery_percentage_min_threshold,
	&dev_ctx.power_config_attr.battery_percentage_threshold1,
	&dev_ctx.power_config_attr.battery_percentage_threshold2,
	&dev_ctx.power_config_attr.battery_percentage_threshold3,
	&dev_ctx.power_config_attr.battery_alarm_state);
#endif

#if APP_HAS_SCD4X
#define SCHNEGGI_EXTRA_CLUSTER CONCENTRATION_MEASUREMENT
#define SCHNEGGI_EXTRA_ATTR_LIST concentration_measurement_attr_list
#define SCHNEGGI_EXTRA_REPORT_COUNT ZB_ZCL_CONCENTRATION_MEASUREMENT_REPORT_ATTR_COUNT
#define SCHNEGGI_DEVICE_VERSION 2
#else
#define SCHNEGGI_EXTRA_CLUSTER POWER_CONFIG
#define SCHNEGGI_EXTRA_ATTR_LIST power_config_attr_list
#define SCHNEGGI_EXTRA_REPORT_COUNT ZB_ZCL_POWER_CONFIG_REPORT_ATTR_COUNT
#define SCHNEGGI_DEVICE_VERSION 1
#endif

ZB_DECLARE_SCHNEGGI_CLUSTER_LIST(
	schneggi_clusters,
	basic_attr_list,
	identify_attr_list,
	temp_measurement_attr_list,
	humidity_measurement_attr_list,
	SCHNEGGI_EXTRA_CLUSTER,
	SCHNEGGI_EXTRA_ATTR_LIST);

ZB_DECLARE_SCHNEGGI_EP(
	schneggi_ep, SCHNEGGI_ENDPOINT, schneggi_clusters,
	SCHNEGGI_EXTRA_CLUSTER, SCHNEGGI_EXTRA_REPORT_COUNT, SCHNEGGI_DEVICE_VERSION);

extern zb_af_endpoint_desc_t zigbee_fota_client_ep;
BUILD_ASSERT(SCHNEGGI_ENDPOINT != CONFIG_ZIGBEE_FOTA_ENDPOINT);
#if APP_HAS_SCD4X
BUILD_ASSERT(SCHNEGGI_SCD4X_TEMPERATURE_ENDPOINT != SCHNEGGI_ENDPOINT);
BUILD_ASSERT(SCHNEGGI_SCD4X_TEMPERATURE_ENDPOINT != CONFIG_ZIGBEE_FOTA_ENDPOINT);
ZB_DECLARE_SCHNEGGI_TEMPERATURE_CLUSTER_LIST(
	scd_temperature_clusters, basic_attr_list, scd_identify_attr_list, scd_temperature_attr_list);
ZB_DECLARE_SCHNEGGI_TEMPERATURE_EP(
	scd_temperature_ep, SCHNEGGI_SCD4X_TEMPERATURE_ENDPOINT, scd_temperature_clusters);
ZBOSS_DECLARE_DEVICE_CTX_3_EP(
	device_ctx, zigbee_fota_client_ep, schneggi_ep, scd_temperature_ep);
#else
ZBOSS_DECLARE_DEVICE_CTX_2_EP(
	device_ctx,
	zigbee_fota_client_ep,
	schneggi_ep);
#endif

// ADC
#if !APP_HAS_SCD4X
static const struct adc_dt_spec battery_adc = ADC_DT_SPEC_GET(DT_PATH(vbatt));
#endif

static const struct device *shtc3;
static const struct i2c_dt_spec shtc3_bus =
	I2C_DT_SPEC_GET(DT_COMPAT_GET_ANY_STATUS_OKAY(sensirion_shtcx));

#define LED_NODE DT_ALIAS(led)
static const struct gpio_dt_spec led_spec = GPIO_DT_SPEC_GET(LED_NODE, gpios);
static const struct gpio_dt_spec battery_monitor_enable = GPIO_DT_SPEC_GET(DT_PATH(vbatt), power_gpios);

#if !APP_HAS_SCD4X
static struct app_battery battery = {
	.adc = &battery_adc,
	.enable = &battery_monitor_enable,
};

static bool battery_monitor_ready;
#endif

#if APP_HAS_SCD4X
static const struct device *scd = DEVICE_DT_GET_ANY(sensirion_scd4x);
#else
static const struct device *scd;
#endif

LOG_MODULE_REGISTER(app, LOG_LEVEL_DBG);

static struct app_environment environment;
#if APP_HAS_SCD4X
static struct app_environment_report scd_temperature;
#endif

static void init_shtc3_device(void)
{
	// Get a device structure from a devicetree node with compatible "sensirion,shtcx".
	shtc3 = DEVICE_DT_GET_ANY(sensirion_shtcx);

	if (shtc3 == NULL)
	{
		LOG_ERR("Error: No devicetree node found for Sensirion SHTCx.");
		return;
	}

	if (!device_is_ready(shtc3))
	{
		LOG_ERR("Device %s is not ready", shtc3->name);
		return;
	}

	LOG_DBG("Found device %s.", shtc3->name);
}

static void init_scd4x_device(void)
{
	if (!APP_HAS_SCD4X)
	{
		LOG_INF("SCD4X disabled by devicetree");
		return;
	}

	if (scd == NULL || device_is_ready(scd) == false)
	{
		LOG_ERR("Failed to initialize SCD4X device");
	}
	else
	{
		LOG_DBG("Found device %s.", scd->name);
	}
}

static void init_battery_monitor(void)
{
	int err;
	if (!gpio_is_ready_dt(&battery_monitor_enable))
	{
		LOG_ERR("Battery monitor GPIO not ready");
		return;
	}
	err = gpio_pin_configure_dt(&battery_monitor_enable, GPIO_OUTPUT_INACTIVE);
	if (err < 0)
	{
		LOG_ERR("Could not configure battery monitor GPIO (%d)", err);
		return;
	}
#if !APP_HAS_SCD4X
	if (!adc_is_ready_dt(&battery_adc))
	{
		LOG_ERR("Battery ADC not ready");
		return;
	}
	err = adc_channel_setup_dt(&battery_adc);
	if (err < 0)
	{
		LOG_ERR("Could not set up battery ADC (%d)", err);
		return;
	}

	battery_monitor_ready = true;
#endif
}

/**@brief Function for initializing all clusters attributes.
 */
static void init_clusters_attr(void)
{
	/* Basic cluster attributes data */
	dev_ctx.basic_attr.zcl_version = ZB_ZCL_VERSION;
	dev_ctx.basic_attr.power_source = APP_HAS_SCD4X ?
		ZB_ZCL_BASIC_POWER_SOURCE_DC_SOURCE : ZB_ZCL_BASIC_POWER_SOURCE_BATTERY;
	dev_ctx.basic_attr.app_version = 0x01;
	dev_ctx.basic_attr.stack_version = 0x03;
	dev_ctx.basic_attr.hw_version = 0x01;
	ZB_ZCL_SET_STRING_VAL(dev_ctx.basic_attr.sw_ver, CONFIG_MCUBOOT_IMGTOOL_SIGN_VERSION,
		ZB_ZCL_STRING_CONST_SIZE(CONFIG_MCUBOOT_IMGTOOL_SIGN_VERSION));

	ZB_ZCL_SET_STRING_VAL(
		dev_ctx.basic_attr.mf_name,
		SCHNEGGI_BASIC_MANUF_NAME,
		ZB_ZCL_STRING_CONST_SIZE(SCHNEGGI_BASIC_MANUF_NAME));

	ZB_ZCL_SET_STRING_VAL(
		dev_ctx.basic_attr.model_id,
		SCHNEGGI_BASIC_MODEL_ID,
		ZB_ZCL_STRING_CONST_SIZE(SCHNEGGI_BASIC_MODEL_ID));

	ZB_ZCL_SET_STRING_VAL(dev_ctx.basic_attr.date_code, SCHNEGGI_BASIC_DATE_CODE,
						  ZB_ZCL_STRING_CONST_SIZE(SCHNEGGI_BASIC_DATE_CODE));

	/* Identify cluster attributes data */
	dev_ctx.identify_attr.identify_time =
		ZB_ZCL_IDENTIFY_IDENTIFY_TIME_DEFAULT_VALUE;

#if !APP_HAS_SCD4X
	/* Battery power configuration */
	dev_ctx.power_config_attr.battery_voltage = ZB_ZCL_POWER_CONFIG_BATTERY_VOLTAGE_INVALID;
	dev_ctx.power_config_attr.battery_percentage_remaining = ZB_ZCL_POWER_CONFIG_BATTERY_REMAINING_UNKNOWN;
	dev_ctx.power_config_attr.battery_size = ZB_ZCL_POWER_CONFIG_BATTERY_SIZE_DEFAULT_VALUE;
	dev_ctx.power_config_attr.battery_quantity = 1;
#endif

	/* Temperature */
	dev_ctx.temp_measure_attrs.measure_value = ZB_ZCL_ATTR_TEMP_MEASUREMENT_VALUE_UNKNOWN;
	dev_ctx.temp_measure_attrs.min_measure_value = ZB_ZCL_TEMP_MEASUREMENT_MIN_VALUE_DEFAULT_VALUE;
	dev_ctx.temp_measure_attrs.max_measure_value = ZB_ZCL_TEMP_MEASUREMENT_MAX_VALUE_DEFAULT_VALUE;
	dev_ctx.temp_measure_attrs.tolerance = ZB_ZCL_ATTR_TEMP_MEASUREMENT_TOLERANCE_MAX_VALUE;

#if APP_HAS_SCD4X
	/* SCD4x temperature is independent of the SHTC3 ambient reading. */
	dev_ctx.scd_temperature_attrs = dev_ctx.temp_measure_attrs;
	dev_ctx.scd_identify_attrs.identify_time = ZB_ZCL_IDENTIFY_IDENTIFY_TIME_DEFAULT_VALUE;
#endif

	/* Humidity */
	dev_ctx.humidity_measure_attrs.measure_value = ZB_ZCL_ATTR_REL_HUMIDITY_MEASUREMENT_VALUE_UNKNOWN;
	dev_ctx.humidity_measure_attrs.min_measure_value =
		ZB_ZCL_REL_HUMIDITY_MEASUREMENT_MIN_VALUE_DEFAULT_VALUE;
	dev_ctx.humidity_measure_attrs.max_measure_value =
		ZB_ZCL_REL_HUMIDITY_MEASUREMENT_MAX_VALUE_DEFAULT_VALUE;

	/* CO2 */
	dev_ctx.concentration_measure_attrs.measure_value =
		ZB_ZCL_ATTR_CONCENTRATION_MEASUREMENT_VALUE_UNKNOWN;
	dev_ctx.concentration_measure_attrs.min_measure_value =
		ZB_ZCL_CONCENTRATION_MEASUREMENT_MIN_VALUE_DEFAULT_VALUE;
	dev_ctx.concentration_measure_attrs.max_measure_value =
		ZB_ZCL_CONCENTRATION_MEASUREMENT_MAX_VALUE_DEFAULT_VALUE;
	dev_ctx.concentration_measure_attrs.tolerance =
		co2_zcl_single_from_float(co2_zcl_fraction_from_ppm(100.0));
}

static bool identifying;

static void stop_identifying(void)
{
	identifying = false;
	gpio_pin_set_dt(&led_spec, 0);
}

static void toggle_identify_led(zb_uint8_t unused)
{
	ZVUNUSED(unused);
	/* A callback already dequeued when Identify stops must not restart blinking. */
	if (!identifying)
	{
		return;
	}
	gpio_pin_toggle_dt(&led_spec);
	if (app_alarm_replace(toggle_identify_led, 0, 100) != RET_OK)
	{
		LOG_WRN("Unable to schedule Identify blink");
		stop_identifying();
	}
}

static void identify_cb(zb_uint8_t active)
{
#if APP_HAS_SCD4X
	/* Both endpoints identify the same physical device. Ending one endpoint's
	 * timer must not stop the LED while the other is still identifying.
	 */
	active = dev_ctx.identify_attr.identify_time != 0 ||
		 dev_ctx.scd_identify_attrs.identify_time != 0;
#endif
	if (active)
	{
		if (identifying) {
			return;
		}
		LOG_INF("Start identify");
		identifying = true;
		gpio_pin_set_dt(&led_spec, 1);
		if (app_alarm_replace(toggle_identify_led, 0, 100) != RET_OK)
		{
			LOG_WRN("Unable to start Identify blink");
			stop_identifying();
		}
	}
	else
	{
		LOG_INF("Stop identify");
		stop_identifying();
		ZB_SCHEDULE_APP_ALARM_CANCEL(toggle_identify_led, ZB_ALARM_ALL_CB);
	}
}

static void update_sensor_values(uint32_t current_cycle)
{
	if (shtc3 != NULL && device_is_ready(shtc3))
	{
		app_environment_update(&environment, shtc3, &shtc3_bus,
				       SCHNEGGI_ENDPOINT, current_cycle, SENSOR_REFRESH_CYCLES);
	}
	else
	{
		LOG_WRN("SHTC3 device not ready, keeping previous values");
	}

#if APP_HAS_SCD4X
	if (scd != NULL && device_is_ready(scd)) {
		app_scd4x_update(&scd_temperature, scd, SCHNEGGI_ENDPOINT,
				SCHNEGGI_SCD4X_TEMPERATURE_ENDPOINT,
				current_cycle, SENSOR_REFRESH_CYCLES);
	} else {
		LOG_WRN("SCD4X device not ready, keeping previous values");
	}
#endif
}

static uint32_t measurement_cycles = 0;

static void sensor_loop(zb_bufid_t bufid)
{
	ZVUNUSED(bufid);
	uint32_t current_cycle = measurement_cycles++;

#if APP_HAS_SCD4X
	LOG_DBG("-- Loop %" PRIu32 " (%s)--", current_cycle, ZB_JOINED() ? "Connected" : "Disconnected");
#else
	LOG_DBG("-- Loop %" PRIu32 " / %" PRIu32 " (%s)--", current_cycle, BATTERY_SLEEP_CYCLES, ZB_JOINED() ? "Connected" : "Disconnected");
#endif

	if (app_alarm_replace(sensor_loop, 0, SLEEP_INTERVAL_SECONDS * 1000U) != RET_OK)
	{
		LOG_ERR("Unable to schedule sensor measurements; restarting");
		app_reboot();
		return;
	}

	update_sensor_values(current_cycle);

#if !APP_HAS_SCD4X
	if (battery_monitor_ready)
	{
		app_battery_update(&battery, SCHNEGGI_ENDPOINT, current_cycle, BATTERY_SLEEP_CYCLES);
	}
#endif

#if APP_HAS_SCD4X
	LOG_DBG("Next measurement in %" PRIu32 " seconds", SLEEP_INTERVAL_SECONDS);
#else
	LOG_DBG("Sleep for %" PRIu32 " seconds", SLEEP_INTERVAL_SECONDS);
#endif
}

void zboss_signal_handler(zb_uint8_t param)
{
	zb_zdo_app_signal_hdr_t *header = NULL;
	zb_zdo_app_signal_type_t signal = zb_get_app_signal(param, &header);
	zb_ret_t status = ZB_GET_APP_SIGNAL_STATUS(param);
	enum app_zigbee_signal app_signal = APP_ZIGBEE_SIGNAL_OTHER;
	bool parent_link_failure = false;

	switch (signal)
	{
	case ZB_ZDO_SIGNAL_SKIP_STARTUP:
		LOG_DBG("Zigbee stack startup: %d", status);
		app_signal = APP_ZIGBEE_SIGNAL_SKIP_STARTUP;
		break;
	case ZB_BDB_SIGNAL_DEVICE_FIRST_START:
		LOG_DBG("First device startup: %d", status);
		app_signal = APP_ZIGBEE_SIGNAL_DEVICE_FIRST_START;
		break;
	case ZB_BDB_SIGNAL_DEVICE_REBOOT:
		LOG_INF("Reboot rejoin result: %d", status);
		app_signal = APP_ZIGBEE_SIGNAL_DEVICE_REBOOT;
		break;
	case ZB_BDB_SIGNAL_STEERING:
		LOG_INF("Network steering result: %d", status);
		app_signal = APP_ZIGBEE_SIGNAL_STEERING;
		break;
	case ZB_ZDO_SIGNAL_LEAVE:
		LOG_INF("Network leave result: %d", status);
		app_signal = APP_ZIGBEE_SIGNAL_LEAVE;
		break;
	case ZB_COMMON_SIGNAL_CAN_SLEEP:
		app_signal = APP_ZIGBEE_SIGNAL_CAN_SLEEP;
		break;
	case ZB_ZDO_SIGNAL_PRODUCTION_CONFIG_READY:
		LOG_DBG("Production config result: %d", status);
		break;
	case ZB_NLME_STATUS_INDICATION:
	{
		zb_zdo_signal_nlme_status_indication_params_t *indication =
			ZB_ZDO_SIGNAL_GET_PARAMS(header, zb_zdo_signal_nlme_status_indication_params_t);
		parent_link_failure =
			indication->nlme_status.status == ZB_NWK_COMMAND_STATUS_PARENT_LINK_FAILURE;
		if (parent_link_failure)
		{
			LOG_WRN("Parent link failure");
		}
		app_signal = APP_ZIGBEE_SIGNAL_NLME_STATUS_INDICATION;
		break;
	}
	default:
		LOG_INF("Unhandled signal %d. Status: %d", signal, status);
		break;
	}

	app_network_handle_signal(app_signal, status == RET_OK, parent_link_failure,
				  sensor_loop, !APP_HAS_SCD4X);

	/* Process leave/rejoin actions before OTA may reboot to reset its session. */
	app_ota_signal(param);
	if (param)
	{
		zb_buf_free(param);
	}
}

int main(void)
{
	LOG_INF("Schneggi sensor starting...");
	if (app_ota_init() != 0) {
		LOG_ERR("OTA/watchdog initialization failed");
		app_reboot();
		return -1;
	}

	/* Only the non-CO2 profiles enable runtime PM. TWIM takes/releases a
	 * runtime reference for each transfer, including sensor sleep cleanup.
	 */
	if (IS_ENABLED(CONFIG_PM_DEVICE_RUNTIME)) {
		int err = pm_device_runtime_enable(shtc3_bus.bus);
		if (err < 0) {
			LOG_ERR("Could not enable I2C runtime PM (%d)", err);
		}
	}

	init_shtc3_device();

	init_scd4x_device();

	/* Keep the divider disabled even when the USB profile never samples it. */
	init_battery_monitor();

	gpio_pin_configure_dt(&led_spec, GPIO_OUTPUT_INACTIVE);

	/* Power off unused sections of RAM to lower device power consumption. */
	if (IS_ENABLED(CONFIG_RAM_POWER_DOWN_LIBRARY))
	{
		LOG_DBG("Enable power down unused ram");
		power_down_unused_ram();
	}

	LOG_DBG("802.15.4 transmit power: %d dBm", nrf_802154_tx_power_get());
	LOG_DBG("ZB sleep threshold: %d ms", zb_get_sleep_threshold());

	/* The USB-powered CO2 device listens continuously; the battery variant sleeps. */
	app_ota_set_sleepy(!APP_HAS_SCD4X);
	zb_set_rx_on_when_idle(APP_HAS_SCD4X ? ZB_TRUE : ZB_FALSE);
	LOG_INF("Zigbee receiver on while idle: %s", APP_HAS_SCD4X ? "yes" : "no");

	// https://developer.nordicsemi.com/nRF_Connect_SDK/doc/zboss/3.11.2.1/zigbee_prog_principles.html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
	zb_set_ed_timeout(APP_ZIGBEE_ED_TIMEOUT_VALUE);
	zb_set_keepalive_timeout(ZB_MILLISECONDS_TO_BEACON_INTERVAL(APP_ZIGBEE_KEEPALIVE_TIMEOUT_MS));
#if APP_HAS_SCD4X
	LOG_INF("Zigbee power profile: receiver on, keepalive=%u ms ed_timeout=%s",
		 APP_ZIGBEE_KEEPALIVE_TIMEOUT_MS, APP_ZIGBEE_ED_TIMEOUT_DESC);
#else
	LOG_INF("Zigbee power profile: long poll=%u ms keepalive=%u ms ed_timeout=%s",
		 APP_ZIGBEE_LONG_POLL_INTERVAL_MS,
		 APP_ZIGBEE_KEEPALIVE_TIMEOUT_MS,
		 APP_ZIGBEE_ED_TIMEOUT_DESC);
#endif

	ZB_AF_REGISTER_DEVICE_CTX(&device_ctx);

	init_clusters_attr();

	ZB_AF_SET_IDENTIFY_NOTIFICATION_HANDLER(SCHNEGGI_ENDPOINT, identify_cb);
#if APP_HAS_SCD4X
	ZB_AF_SET_IDENTIFY_NOTIFICATION_HANDLER(SCHNEGGI_SCD4X_TEMPERATURE_ENDPOINT, identify_cb);
#endif

	// Erase persistent storage
	zb_set_nvram_erase_at_start(ZB_FALSE);

	app_ota_startup_ready(device_is_ready(shtc3) &&
		(!APP_HAS_SCD4X || (scd != NULL && device_is_ready(scd)))
#if !APP_HAS_SCD4X
		&& battery_monitor_ready && adc_is_ready_dt(&battery_adc)
#endif
	);
	zigbee_enable();

	LOG_INF("Schneggi sensor started");

	k_sleep(K_FOREVER);

	return -1;
}

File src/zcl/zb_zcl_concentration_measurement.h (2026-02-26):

/*
 * Copyright (c) 2023 Jan Gnip
 * ZBOSS Zigbee 3.0
 *
 * Copyright (c) 2012-2022 DSR Corporation, Denver CO, USA.
 * www.dsr-zboss.com
 * www.dsr-corporation.com
 * All rights reserved.
 *
 *
 * Use in source and binary forms, redistribution in binary form only, with
 * or without modification, are permitted provided that the following conditions
 * are met:
 *
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
 * 2. Neither the name of Nordic Semiconductor ASA nor the names of its
 *    contributors may be used to endorse or promote products derived from this
 *    software without specific prior written permission.
 *
 * 3. This software, with or without modification, must only be used with a Nordic
 *    Semiconductor ASA integrated circuit.
 *
 * 4. Any software provided in binary form under this license must not be reverse
 *    engineered, decompiled, modified and/or disassembled.
 *
 * THIS SOFTWARE IS PROVIDED BY NORDIC SEMICONDUCTOR ASA "AS IS" AND ANY EXPRESS OR
 * IMPLIED WARRANTIES, INCLUDING, BUT NOT LIMITED TO, THE IMPLIED WARRANTIES OF
 * MERCHANTABILITY, NONINFRINGEMENT, AND FITNESS FOR A PARTICULAR PURPOSE ARE
 * DISCLAIMED. IN NO EVENT SHALL NORDIC SEMICONDUCTOR ASA OR CONTRIBUTORS BE LIABLE
 * FOR ANY DIRECT, INDIRECT, INCIDENTAL, SPECIAL, EXEMPLARY, OR CONSEQUENTIAL
 * DAMAGES (INCLUDING, BUT NOT LIMITED TO, PROCUREMENT OF SUBSTITUTE GOODS OR
 * SERVICES; LOSS OF USE, DATA, OR PROFITS; OR BUSINESS INTERRUPTION) HOWEVER
 * CAUSED AND ON ANY THEORY OF LIABILITY, WHETHER IN CONTRACT, STRICT LIABILITY, OR
 * TORT (INCLUDING NEGLIGENCE OR OTHERWISE) ARISING IN ANY WAY OUT OF THE USE OF
 * THIS SOFTWARE, EVEN IF ADVISED OF THE POSSIBILITY OF SUCH DAMAGE.
 */
/* PURPOSE: Concentration Measurement cluster defintions
*/

#define ZCL_CO2_MEASUREMENT_MEASURED_VALUE_MULTIPLIER 0.000001

#define AIR_QUALITY_MONITOR_ENDPOINT_NB 1

#ifndef ZB_ZCL_CONCENTRATION_MEASUREMENT_H
#define ZB_ZCL_CONCENTRATION_MEASUREMENT_H 1

#include <zboss_api.h>
#include <zboss_api_addons.h>

/** @cond DOXYGEN_ZCL_SECTION */

/** @addtogroup ZB_ZCL_WATER_CONTENT_MEASUREMENT
 *  @{
 */

/* Cluster ZB_ZCL_WATER_CONTENT_MEASUREMENT */

/*! @name Water Content Measurement cluster attributes
    @{
*/

/*! @brief Water Content Measurement cluster attribute identifiers
    @see ZCL specification revision 7, Concentration MeasuremenWater Content Measurement Cluster 4.7.2.1
*/
enum zb_zcl_concentration_measurement_attr_e
{
  /** @brief MeasuredValue, ZCL specification revision 7 subsection 4.7.2.1.1 MeasuredValue Attribute */
  ZB_ZCL_ATTR_CONCENTRATION_MEASUREMENT_VALUE_ID     = 0x0000,
  /** @brief MinMeasuredValue, ZCL specification revision 7 subsection 4.7.2.1.2 MinMeasuredValue Attribute*/
  ZB_ZCL_ATTR_CONCENTRATION_MEASUREMENT_MIN_VALUE_ID = 0x0001,
  /** @brief MaxMeasuredValue, ZCL specification revision 7 subsection 4.7.2.1.3 MaxMeasuredValue Attribute*/
  ZB_ZCL_ATTR_CONCENTRATION_MEASUREMENT_MAX_VALUE_ID = 0x0002,
  /** The Tolerance attribute SHALL indicate the magnitude of the
   *  possible error that is associated with MeasuredValue, using
   *  the same units and resolution.
   *  @brief Tolerance, ZCL specification revision 7 subsection 4.7.2.1.4 Tolerance Attribute
   */
  ZB_ZCL_ATTR_CONCENTRATION_MEASUREMENT_TOLERANCE_ID             = 0x0003,
};

/** @brief CO2 cluster ID, ZCL specification revision 8 subsection 4.13.1.3 Cluster Identifiers */
#define ZB_ZCL_CLUSTER_ID_CONCENTRATION_MEASUREMENT 0x040D

/** @brief Default value for Concentration cluster revision global attribute */
#define ZB_ZCL_CONCENTRATION_MEASUREMENT_CLUSTER_REVISION_DEFAULT ((zb_uint16_t)0x0002u)

/** @brief SINGLE-precision helper constants (IEEE754, little-endian raw) */
#define ZB_ZCL_CONCENTRATION_MEASUREMENT_SINGLE_NAN  ((zb_uint32_t)0x7FC00000u)
#define ZB_ZCL_CONCENTRATION_MEASUREMENT_SINGLE_ZERO ((zb_uint32_t)0x00000000u)
#define ZB_ZCL_CONCENTRATION_MEASUREMENT_SINGLE_ONE  ((zb_uint32_t)0x3F800000u)

/** @brief MeasuredValue attribute unknown value */
#define ZB_ZCL_ATTR_CONCENTRATION_MEASUREMENT_VALUE_UNKNOWN        ZB_ZCL_CONCENTRATION_MEASUREMENT_SINGLE_NAN

/** @brief MinMeasuredValue attribute minimum value */
#define ZB_ZCL_ATTR_CONCENTRATION_MEASUREMENT_MIN_VALUE_MIN_VALUE  ZB_ZCL_CONCENTRATION_MEASUREMENT_SINGLE_ZERO

/** @brief MinMeasuredValue attribute maximum value */
#define ZB_ZCL_ATTR_CONCENTRATION_MEASUREMENT_MIN_VALUE_MAX_VALUE  ZB_ZCL_CONCENTRATION_MEASUREMENT_SINGLE_ONE

/** @brief MinMeasuredValue attribute undefined value */
#define ZB_ZCL_ATTR_CONCENTRATION_MEASUREMENT_MIN_VALUE_UNDEFINED  ZB_ZCL_CONCENTRATION_MEASUREMENT_SINGLE_NAN

/** @brief MaxMeasuredValue attribute minimum value */
#define ZB_ZCL_ATTR_CONCENTRATION_MEASUREMENT_MAX_VALUE_MIN_VALUE  ZB_ZCL_CONCENTRATION_MEASUREMENT_SINGLE_ZERO

/** @brief MaxMeasuredValue attribute maximum value */
#define ZB_ZCL_ATTR_CONCENTRATION_MEASUREMENT_MAX_VALUE_MAX_VALUE  ZB_ZCL_CONCENTRATION_MEASUREMENT_SINGLE_ONE

/** @brief MaxMeasuredValue attribute value not defined */
#define ZB_ZCL_ATTR_CONCENTRATION_MEASUREMENT_MAX_VALUE_UNDEFINED  ZB_ZCL_CONCENTRATION_MEASUREMENT_SINGLE_NAN

/** @brief Default value for MeasurementValue attribute */
#define ZB_ZCL_CONCENTRATION_MEASUREMENT_VALUE_DEFAULT_VALUE ZB_ZCL_CONCENTRATION_MEASUREMENT_SINGLE_NAN

/** @brief Default value for MeasurementMinValue attribute */
#define ZB_ZCL_CONCENTRATION_MEASUREMENT_MIN_VALUE_DEFAULT_VALUE ZB_ZCL_CONCENTRATION_MEASUREMENT_SINGLE_NAN

/** @brief Default value for MeasurementMaxValue attribute */
#define ZB_ZCL_CONCENTRATION_MEASUREMENT_MAX_VALUE_DEFAULT_VALUE ZB_ZCL_CONCENTRATION_MEASUREMENT_SINGLE_NAN

/** @brief Tolerance attribute minimum value */
#define ZB_ZCL_ATTR_CONCENTRATION_MEASUREMENT_TOLERANCE_MIN_VALUE            0x0000

/** @brief Tolerance attribute maximum value */
#define ZB_ZCL_ATTR_CONCENTRATION_MEASUREMENT_TOLERANCE_MAX_VALUE            0x0800

/** @cond internals_doc */
/*! @internal @name Concentration Measurement cluster internals
    Internal structures for attribute representation in cluster definitions.
    @{
*/

#define ZB_SET_ATTR_DESCR_WITH_ZB_ZCL_ATTR_CONCENTRATION_MEASUREMENT_VALUE_ID(data_ptr) \
{                                                               \
  ZB_ZCL_ATTR_CONCENTRATION_MEASUREMENT_VALUE_ID,                \
  ZB_ZCL_ATTR_TYPE_SINGLE,                                         \
  ZB_ZCL_ATTR_ACCESS_READ_ONLY | ZB_ZCL_ATTR_ACCESS_REPORTING,  \
  ZB_ZCL_NON_MANUFACTURER_SPECIFIC,                             \
  (void*) data_ptr                                         \
}

#define ZB_SET_ATTR_DESCR_WITH_ZB_ZCL_ATTR_CONCENTRATION_MEASUREMENT_MIN_VALUE_ID(data_ptr) \
{                                                       \
  ZB_ZCL_ATTR_CONCENTRATION_MEASUREMENT_MIN_VALUE_ID,    \
  ZB_ZCL_ATTR_TYPE_SINGLE,                                 \
  ZB_ZCL_ATTR_ACCESS_READ_ONLY,                         \
  ZB_ZCL_NON_MANUFACTURER_SPECIFIC,                     \
  (void*) data_ptr                                 \
}
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

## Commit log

2023-11-21 Initial version
    [BOM-E73-2G4M08S1C-52840.csv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]
2023-11-21 Optimize for battery life
2023-11-30 Lower power consumption
2024-02-09 Set Q size to 128, long poll to 60s, schedule sensor loop after zigbee is intialized
2024-02-16 Remove PWM, Disable UART
2024-02-18 Update README.md for power consumption
2024-08-29 Add V1.1 with CO2 support (#2)
    V1.1
    Smaller outline
    Remove USB-C and physical switch
    Improve signal strength
    Add PH connector for additional sensor boards
    Add CO2 board
    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
    [BOM-E73-2G4M08S1C-52840.csv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]
2024-10-05 Add Kicad files for 1.1 (#4)
    [BOM-E73-2G4M08S1C-52840.csv, BOM-schneggi_sensor_kicad7.csv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]
2024-10-05 Improve broken rejoin (#3)
    [main.c]
2025-01-31 Add new Case (#5)
    [Ultimate_Box.scad, back.stl, bottom.stl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]
2026-02-18 Fix Zigbee lifecycle handling; add tests/CI and sensor fallback (#11)
    * Fix Zigbee steering flow and add Makefile tasks
    * Add Zigbee signal unit tests and run them in CI
    * Add gitignore for local build and KiCad artifacts
    * CI: run host unit tests via gcc script in container
    * CI: align toolchain container with NCS v2.5.2
    * CI: use available NCS 2.5.x toolchain container tag
    * Refine Zigbee reboot lifecycle handling and diagnostics
    * Keep last Zigbee sensor values when sensors are unavailable
    [main.c]
2026-02-18 Fix critical Zigbee sensor bugs and harden build workflow
    [main.c, zb_zcl_concentration_measurement.h]
2026-02-18 Fix timing overflow and invalid battery cycle config
    [main.c]
2026-02-18 Include ram_pwrdn header to fix implicit declaration
    [main.c]
2026-02-24 Add balanced Zigbee power profile defaults (#14)
2026-02-26 NCS migration to v2.9.2 with Zigbee/SHTCx compatibility updates (#10)
    * docs: add NCS migration strategy for Zigbee sensor
    * docs: add NCS migration validation checklist
    * build: bump NCS revision to v2.6.0
    * fix: adapt custom concentration attr macros for NCS v2.6 ZBOSS struct
    * docs: log migration step from v2.5.2 to v2.6.0
    * build: bump NCS revision to v2.7.0
    * docs: log migration step from v2.6.0 to v2.7.0
    * build: bump NCS revision to v2.8.0
    * fix: update SHTCx devicetree for NCS v2.8
    * build: bump NCS revision to v2.9.2
    * docs: log migration step from v2.8.0 to v2.9.2
    * docs: record blocked hardware validation status for v2.9.2
    * ci: use CONF_FILE for debug build config
    *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
    [zb_zcl_concentration_measurement.h]
2026-02-27 Build: switch to pure west workflow (#16)
    * build: switch to pure west workflow and fix flash defaults
    * docs: update README for pure west workflow
2026-03-22 Optimize battery-powered sensor reporting (#18)
    * Fix battery reporting cadence rounding
    * Optimize battery-powered sensor reporting
    * Fix stale Zigbee attribute values
    [main.c]
2026-04-19 Improve Zigbee rejoin recovery and build targets (#19)
    * Improve Zigbee rejoin recovery and build targets
    * Ignore local build and Codex artifacts
    * Fix Zigbee long poll interval units
    * Avoid forced steering on parent link failure
    * Add unit coverage for rejoin state machine
    [main.c]
2026-05-03 Add flash adapter PCB production files
    [BOM-flash_adapter.csv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]
2026-05-06 Add flash adapter silkscreen logo
    [flash_adapter-B_Cu.gbl, flash_adapter-B_Mask.gbs, flash_adapter-B_Paste.gbp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]
2026-07-21 Refactor and harden firmware measurement logic (#20)
    * Extract measurement reporting logic
    * Extract battery value conversions
    * Extract ZCL report adapter
    * Split sensor update paths
    * Split battery report updates
    * Harden battery ADC conversion
    * Harden Zigbee startup failure handling
    * Saturate battery ZCL attribute conversions
    * Test ZCL report attribute mapping
    [main.c]
2026-09-11 Harden firmware retries, battery handling, and build validation (#21)
    * Harden rejoin retries, battery handling, and build validation
    * Reduce battery-profile idle power and extend outage backoff
    * Regenerate build caches after NCS workspace changes
    * Add reproducible case models and fit checks
    * Ignore local Codex state path
    [assembly.stl, pcb.stl]
2026-10-03 Use USB power profile for CO2 sensors (#23)
    Advertise DC power, omit battery reporting, keep the receiver on, and version CO2 firmware 2.0.0. Clarify signing and ZHA OTA documentation.
2026-10-04 Honor ZHA reporting settings for temperature and humidity (#24)
    Honor coordinator-configured Zigbee reporting for temperature and humidity while retaining the legacy fallback after a reporting reset. Bump OTA versions to 2.0.2/1.0.4 and document reporting behavior.
    [main.c]
2026-10-04 Improve sensor recovery, OTA packaging, and repository cleanup (#25)
    * Simplify sensor reporting and retry failed battery measurements
    * Validate complete DFU packages and safely replace OTA indexes
    * Install OTA firmware artifacts atomically for safe retries
    * Stop manufacturing exports when PCB rule checks fail
    * Remove deprecated enclosure generator and previews
    * Recover from required Zigbee alarm failures and prevent delay overflow
    [assembly.stl, pcb.stl]
2026-10-04 Prepare release 2.0.3 with battery firmware 1.0.5
2026-10-05 Resume interrupted Zigbee OTA downloads (#27)
    * Resume interrupted Zigbee OTA downloads from committed flash pages
    * Initialize OTA journal access before cold-boot leave handling
2026-10-05 Prepare release 2.0.4 with battery firmware 1.0.6
2026-10-10 Expose SCD40 temperature on a second Zigbee endpoint (#28)
